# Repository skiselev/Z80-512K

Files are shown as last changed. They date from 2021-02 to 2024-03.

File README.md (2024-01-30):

# Z80-512K
Z80 CPU, 512 KiB SRAM, and 512 KiB Flash ROM module for RCBus systems

## Table of Content
* [Overview](#overview)
  * [Specifications](#specifications)
* [Assembly Instructions](#assembly-instructions)
* [Hardware Documentation](#hardware-documentation)
  * [Schematic and PCB Layout](#schematic-and-pcb-layout)
  * [Input/Output Ports](#inputoutput-ports)
  * [Connectors](#connectors)
  * [Bill of Materials](#bill-of-materials)
  * [CPLD Fuse Map](#cpld-fuse-map)
* [Release Notes](#release-notes)
  * [Changes](#changes)
  * [Known Issues](#known-issues)
* [Red Tape](#red-tape)
  * [Licensing](#licensing)
  * [Trademarks](#trademarks)

## Overview
Z80-512K is an RCBus and RC2014* compatible module, designed to run RomWBW firmware including CP/M, ZSDOS, and various applications under these OSes. Z80-512K combines functionality of the following RC2014* modules on a single module, thus saving space on the backplane:
* Z80 CPU Module
* 512k ROM 512k RAM Module
* Clock and Reset Module

In addition to these functions, Z80-512K includes programmable CLK2 clock divider, support for battery-backed SRAM, power failure NMI generation, and a watchdog.

Minimal CP/M computer system can be built using Z80-512K module, a backplane, and a serial port module, such as Z80 SIO or MC68B50 ACIA. For configurable baud rate settings, it is recommened to use serial modules that can use CLK2 as a clock, for example Steve Cousins' [SC716](https://smallcomputercentral.com/sc716-rcbus-z80-sio-2-serial-module/) or [SC725](https://smallcomputercentral.com/sc725-rcbus-serial-and-timer-module/) modules.  Additional storage module is not required, since RomWBW utilizes part of ROM and SRAM for ROM and RAM disks respecitvely, but a Compact Flash module can be added for additional storage. For a compact system, a 3-slot [SC723](https://smallcomputercentral.com/sc723-rcbus-backplane-3/) can be used.

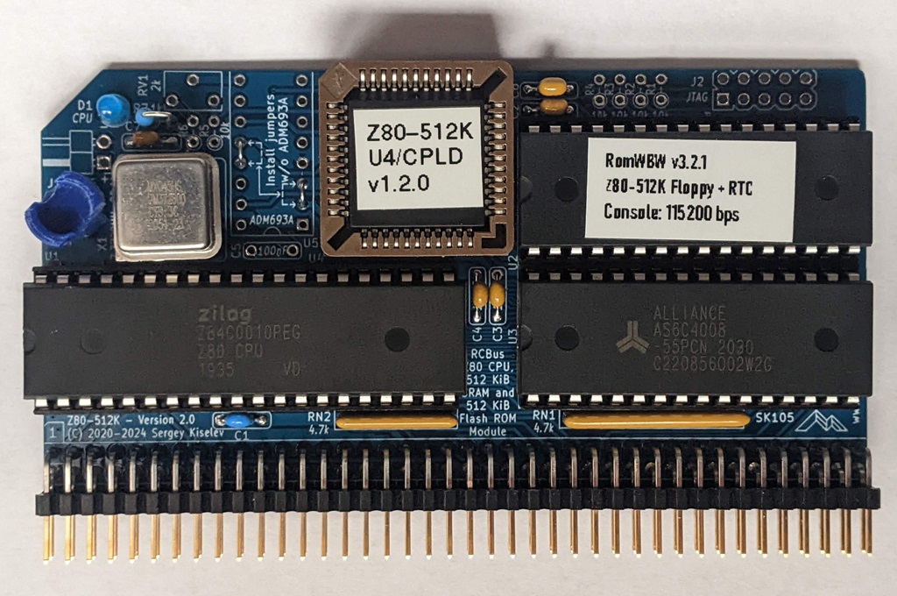
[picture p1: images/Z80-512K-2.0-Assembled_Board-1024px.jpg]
Z80-512K Assembled Board


### Specifications
* Processor: Zilog* Z80 CPU (CMOS version - Z84C00)
* Memory: 512 KiB battery-backed SRAM, 512 KiB Flash ROM, Zeta SBC V2 compatible memory pager
* Bus: RC2014* compatible
* Microprocessor Supervisor:
  * Reset generation
  * SRAM battery backup
  * Power failure NMI
  * Watchdog

## Assembly Instructions

Please refer to [Assembly Instructions](Assembly_Instructions.md) document

## Hardware Documentation

### Documentation for the Previous Versions

* [Version 1.2](https://github.com/skiselev/Z80-512K/tree/v1.2)

### Schematic and PCB Layout

* [Schematic - Version 2.0](KiCad/Z80-512K-Schematic-2.0.pdf)
* [PCB Layout - Version 2.0](KiCad/Z80-512K-Board-2.0.pdf)

### Input/Output Ports
Z80-512K uses an Atmel* ATF1504AS CPLD (complex programmable logic device) to implement Zeta SBC V2 compatible memory pager, watchdog control, and UART clock divider.
These functions are configured using registers that are accessible using I/O ports. Upon reset, the configuration registers are set to values that result in an RC2014 compatible configuration, so that RomWBW RCZ80_std.rom image can be used without any modifications.

The following I/O ports are implemented in the CPLD:

#### 0x6D - CONFIG - UART Clock Divisor and Watchdog Configuration (Read/Write)

Bits 0-4 define the ratio the 7.3728 MHz CPU clock (CLK1) is divided by to produce UART clock (CLK2).
The output clock can be calculated using the following formula: **f<sub>CLK2</sub> (Hz) = 7372800 / (3<sup>m</sup> * 2<sup>n</sup>)**, where **m** is bit 4 of **CONFIG** register (0 or 1), and **n** are bits 3-0 of **CONFIG** register (0 to 15)

Port | Bit # | Function                | Value = 0             | Value = 1
-----|-------|-------------------------|-----------------------|----------------------
0x6D | 0     | Divide CPU clock by 2   | Disable divide by 2   | Enable divide by 2
0x6D | 1     | Divide CPU clock by 4   | Disable divide by 4   | Enable divide by 4
0x6D | 2     | Divide CPU clock by 16  | Disable divide by 16  | Enable divide by 16
0x6D | 3     | Divide CPU clock by 256 | Disable divide by 256 | Enable divide by 256
0x6D | 4     | Divide CPU clock by 3   | Disable divide by 3   | Enable divide by 3

* Note: Bits 0-4 are reset to '0' on power-on or reset, so that the divide ratio is set to 1 and the CLK2 frequency is 7.3728 MHz

Bit 5 enables or disables the watchdog and controls the generation of watchdog (WDOG) signal. On the board the WDOG signal is connected to the CPU supervisor IC U5 ADM693A. The CPU supervisor will reset the board if WDOG signal is not pulsed within 1.6 seconds.
When watchdog is disabled, the /M1 signal is routed to WDOG signal, so that it is pulsed on every instruction fetch. When watchdog is enabled, the WDOG signal should be pulsed by writting to WDOG register, port 0x6F (see below) in intervals of less than 1.6 seconds.

Port | Bit # | Function                | Value = 0             | Value = 1
-----|-------|-------------------------|-----------------------|----------------------
0x6D | 5     | Watchdog enable         | Disable watchdog      | Enable watchdog

* Note: Bit 5 is reset to '0' on power-on or reset, so that watchdog is disabled

Port | Bit # | Function                                         | Value
-----|-------|--------------------------------------------------|-----------------------
0x6D | 7-6   | Not implemented                                  | Should be set to 0

#### 0x6F - WDOG - Reset Watchdog (Write-only)

Any write to this port pulses the WDOG signal, which resets the watchdog in the CPU supervisor U5

Port | Bit # | Function                | Value
-----|-------|-------------------------|---------------------------------------------
0x6F | N/A   | WDOG - Reset watchdog   | Any write to this port resets the watchdog

#### 0x78-0x7B - MPGSEL - Memory Page Select Registers (Write-only)

Port | Bit # | Function                                         | Value
-----|-------|--------------------------------------------------|-----------------------
0x78 | 5-0   | MPGSEL_0 - Page number for bank #0 0x0000-0x3FFF | 0-31 - Page number
0x78 | 7-6   | Not implemented                                  | Should be set to 0
0x79 | 5-0   | MPGSEL_1 - Page number for bank #1 0x4000-0x7FFF | 0-31 - Page number
0x79 | 7-6   | Not implemented                                  | Should be set to 0
0x7A | 5-0   | MPGSEL_3 - Page number for bank #2 0x8000-0xBFFF | 0-31 - Page number
0x7A | 7-6   | Not implemented                                  | Should be set to 0
0x7B | 5-0   | MPGSEL_4 - Page number for bank #3 0xC000-0xFFFF | 0-31 - Page number
0x7B | 7-6   | Not implemented                                  | Should be set to 0

#### 0x7Ch - MPGENA - Enable Memory Paging (Write-only)

Port | Bit # | Function                | Value = 0             | Value = 1
-----|-------|-------------------------|-----------------------|----------------------
0x7C | 0     | Memory paging enable    | Disable memory paging | Enable memory paging

* Note: The register is reset to '0' on power-on or reset, which disables the memory paging. When memory paging is disabled the memory page 0 (lower 16 KiB of the Flash ROM) is mapped to all banks.

Port | Bit # | Function                                         | Value
-----|-------|--------------------------------------------------|-----------------------
0x7C | 7-1   | Not implemented                                  | Should be set to 0

### Connectors

#### J1 - NVRAM Battery
Connect 3V battery for SRAM backup to this connector.

**Important: If the SRAM battery backup is not desired, short J1 with a jumper. Do not leave this connector open.**

Pin | Signal Name | Description
--- | ----------- | -----------
1   | VBAT        | Positive terminal - +3V
2   | GND         | Negative terminal - ground

#### J2 - JTAG - CPLD
This connector can be used to program the U4 CPLD

Pin  | Signal Name | Description      | Pin  | Signal Name | Description
---- | ----------- | ---------------- | ---- | ----------- | ----------------
1    | TCK         | Test Clock       | 2    | GND         | Ground
3    | TDO         | Test Data Output | 4    | 5V          | 5V Power Supply - Output to JTAG adapter
5    | TMS         | Test Mode Select | 6    | NC          | No Connect
7    | NC          | No Connect       | 8    | NC          | No Connect
9    | TDI         | Test Data Input  | 10   | GND         | Ground

#### J3, J4 - RC2014* Bus
Pin   | Signal Name | Description                             | Pin   | Signal Name | Description
----- | ----------- | --------------------------------------- | ----- | ----------- | -----------
J3-1  | A15         | Address A15; Output                     | J3-41 | p41         | Reserved; Not connected
J3-2  | A14         | Address A14; Output                     | J3-42 | /BAI        | Bus Acknowledge In; Not connected
J3-3  | A13         | Address A13; Output                     | J3-43 | /BAO        | Bus Acknowledge Out; Not connected
J3-4  | A12         | Address A12; Output                     | J3-44 | p44         | Reserved; Not connected
J3-5  | A11         | Address A11; Output                     | J3-45 | p45         | Reserved; Not connected
J3-6  | A10         | Address A10; Output                     | J3-46 | p46         | Reserved; Not connected
J3-7  | A9          | Address A9; Output                      | J3-47 | p47         | Reserved; Not connected
J3-8  | A8          | Address A8; Output                      | J3-48 | p48         | Reserved; Not connected
J3-9  | A7          | Address A7; Output                      | J3-49 | A23         | Address A23; Input; Not connected
J3-10 | A6          | Address A6; Output                      | J3-50 | A22         | Address A22; Input; Not connected
J3-11 | A5          | Address A5; Output                      | J3-51 | A21         | Address A21; Input; Not connected
J3-12 | A4          | Address A4; Output                      | J3-52 | A20         | Address A20; Input; Not connected
J3-13 | A3          | Address A3; Output                      | J3-53 | A19         | Address A19; Input; Not connected
J3-14 | A2          | Address A2; Output                      | J3-54 | A18         | Address A18; Input; Not connected
J3-15 | A1          | Address A1; Output                      | J3-55 | A17         | Address A17; Input; Not connected
J3-16 | A0          | Address A0; Output                      | J3-56 | A16         | Address A16; Input; Not connected
J3-17 | GND         | Ground                                  | J3-57 | GND         | Ground
J3-18 | VCC         | Power Supply - +5V                      | J3-58 | VCC         | Power Supply - +5V
J3-19 | /M1         | Machine Cycle One; Output               | J3-59 | /RFSH       | DRAM refresh; Output
J3-20 | /RESET      | Reset; Output                           | J3-60 | PAGE         | Page ROM/RAM input; Not connected
J3-21 | CLK1        | CPU Clock; Output                       | J3-61 | CLK2        | UART Clock (programmable); Output
J3-22 | /INT        | Interrupt; Input                        | J3-62 | /BUSACK     | DMA Bus Acknowledge; Output
J3-23 | /MREQ       | Memory Request; Output                  | J3-63 | /HALT       | Halt; Output
J3-24 | /WR         | Write Request; Output                   | J3-64 | /BUSREQ     | DMA Bus Request; Input
J3-25 | /RD         | Read Request; Output                    | J3-65 | /WAIT       | Wait; Input
J3-26 | /IORQ       | Input/Output Request; Output            | J3-66 | /NMI        | Non-maskable Interrupt; Input
J3-27 | D0          | Data D0; Input/Output                   | J3-67 | D8          | Data D8; Input/Output; Not connected
J3-28 | D1          | Data D1; Input/Output                   | J3-68 | D9          | Data D9; Input/Output; Not connected
J3-29 | D2          | Data D2; Input/Output                   | J3-69 | D10         | Data D10; Input/Output; Not connected
J3-30 | D3          | Data D3; Input/Output                   | J3-70 | D11         | Data D11; Input/Output; Not connected
J3-31 | D4          | Data D4; Input/Output                   | J3-71 | D12         | Data D12; Input/Output; Not connected
J3-32 | D5          | Data D5; Input/Output                   | J3-72 | D13         | Data D13; Input/Output; Not connected
J3-33 | D6          | Data D6; Input/Output                   | J3-73 | D14         | Data D14; Input/Output; Not connected
J3-34 | D7          | Data D7; Input/Output                   | J3-74 | D15         | Data D15; Input/Output; Not connected
J3-35 | TX          | Channel 1, Transmit Data; Not Connected | J3-75 | TX2         | Channel 2, Transmit Data; Not Connected
J3-36 | RX          | Channel 1, Receive Data; Not Connected  | J3-76 | RX2         | Channel 2, Receive Data; Not Connected
J3-37 | /IRQ1       | Interrupt Request 1; Not connected      | J3-77 | /IRQ2       | Interrupt Request 2; Not connected
J3-38 | IEI         | Interrupt Enable In; Not connected      | J3-78 | p78         | Reserved; Not connected
J3-39 | IEO         | Interrupt Enable Out; Not connected     | J3-79 | p79         | Reserved; Not connected
J3-40 | USER4       | User Pin 4; Not connected               | J3-80 | USER8       | User Pin 8; Not connected

### Bill of Materials

#### Version 2.0

Mouser projects - all components except of the PCB:
* [Z80-512K V2 project](https://www.mouser.com/ProjectManager/ProjectDetail.aspx?AccessID=a4dc766274) - All components except of the PCB, CPU supervisor (optional), and JTAG header (optional).
* [Z80-512K V2 - CPU Supervisor project](https://www.mouser.com/ProjectManager/ProjectDetail.aspx?AccessID=bce8da5b24) - Components for CPU supervisor (optional).
* [Z80-512K V2 - JTAG Header project](https://www.mouser.com/ProjectManager/ProjectDetail.aspx?AccessID=c965bd23ef) - Components for JTAG header (optional).

Z80-512K project on Tindie:
* [Complete kit](https://www.tindie.com/products/weird/z80-512k-rcbus-module-kit/).
* [Z80-512K PCB, a preprogrammed CPLD and optionally a Flash ROM](https://www.tindie.com/products/weird/z80-512k-rcbus-module-pcb-and-cpld/).

Component type     | Reference | Description                                 | Quantity | Possible sources and notes 
------------------ | --------- | ------------------------------------------- | -------- | --------------------------
PCB                |           | Z80-512K PCB - Version 2.0                  | 1        | Buy from my Tindie store: [Complete kit](https://www.tindie.com/products/weird/z80-512k-rc2014-compatible-module-kit/); [Z80-512K PCB, a preprogrammed CPLD and optionally a Flash ROM](https://www.tindie.com/products/weird/z80-512k-rc2014-compatible-module-pcb-and-cpld/), or order from a PCB manufacturer of your choice using provided Gerber or KiCad files
Integrated Circuit | U1        | Z84C00xxPEG - Z80 CPU, CMOS, 40 pin DIP     | 1        | Mouser [692-Z84C0010PEG](https://www.mouser.com/ProductDetail/692-Z84C0010PEG)
Integrated Circuit | U2        | SST39SF040 - 512 KiB Flash ROM, 32 pin DIP  | 1        | Mouser [804-39SF0407CPHE](https://www.mouser.com/ProductDetail/804-39SF0407CPHE)
Integrated Circuit | U3        | AS6C4008 - 512 KiB SRAM, 32 pin DIP         | 1        | Mouser [913-AS6C4008-55PCN](https://www.mouser.com/ProductDetail/913-AS6C4008-55PCN)
Integrated Circuit | U4        | ATF1504AS - CPLD, 64 macrocells, 44 pin PLCC| 1        | Mouser [556-AF1504AS10JU44](https://www.mouser.com/ProductDetail/556-AF1504AS10JU44); Possible alternative: Altera EPM7064SLC44-10
Integrated Circuit | U5        | ADM693A - Microprocessor Supervisory Circuit| 1        | Mouser [584-ADM693ANZ](https://www.mouser.com/ProductDetail/584-ADM693ANZ). Optional: CPU reset, watchdog, and power failure NMI. Possible alternatives: MAX693, LTC693, ADM691, MAX691, LTC691, ADM695, MAX695, LTC965, LTC1235
Oscillator         | X1        | 7.3728 MHz, CMOS oscillator, half can       | 1        | Mouser [774-MXO45HS-3C-7.3](https://www.mouser.com/ProductDetail/774-MXO45HS-3C-7.3) or [520-2200B-073](https://www.mouser.com/ProductDetail/520-2200B-073/)
LED                | D1        | LED indicator, 3 mm, blue                   | 1        | Mouser [710-151033BS03000](https://www.mouser.com/ProductDetail/710-151033BS03000)
Connector          | J1        | 2 pin header with friction lock, right angle| 1        | Mouser [571-6404572](https://www.mouser.com/ProductDetail/571-6404572). Optional: battery-backed SRAM
Pin Header         | J2        | 2x5 pin header, 2.54 mm pitch, vertical     | 1        | Mouser [649-77313-118-10LF](https://www.mouser.com/ProductDetail/649-77313-118-10LF). Optional: JTAG header
Pin Header         | J3        | 2x40 pin header, 2.54 mm pitch, right angle | 1        | Mouser [517-5121TG](https://www.mouser.com/ProductDetail/517-5121TG)
Capacitor          | C1        | 10 uF, 25V, MLCC, 5 mm pitch                | 1 | Mouser [810-FG28X5R1E106MR06](https://www.mouser.com/ProductDetail/810-FG28X5R1E106MR06)
Capacitor          | C2 - C7   | 0.1 uF, 50V, MLCC, 5 mm pitch               | 6        | Mouser [594-K104K15X7RF53H5](https://www.mouser.com/ProductDetail/594-K104K15X7RF53H5). Note: C5 is optional, required if U5 installed
Resistor Array     | RN1       | 4.7 kohm, bussed, 9 pin SIP                 | 1        | Mouser [652-4609X-1LF-4.7K](https://www.mouser.com/ProductDetail/652-4609X-1LF-4.7K) or [652-4609X-AP1-472LF](https://www.mouser.com/ProductDetail/652-4609X-AP1-472LF)
Resistor Array     | RN2       | 4.7 kohm, bussed, 6 pin SIP                 | 1        | Mouser [652-4606X-1LF-4.7K](https://www.mouser.com/ProductDetail/652-4606X-1LF-4.7K) or [652-4606X-AP1-472LF](https://www.mouser.com/ProductDetail/652-4606X-AP1-472LF)
Resistor           | R1 - R5   | 10 kohm, 0.25 W, 1% tolerance, axial        | 5        | Mouser [603-MFR-25FRF5210K](https://www.mouser.com/ProductDetail/603-MFR-25FRF5210K). Optional: R1 - R4 - JTAG header, R5 - Power failure NMI	
Resistor           | R6        | 29.4 kohm, 0.25 W, 1% tolerance, axial      | 1        | Mouser [603-MFR-25FBF52-29K4](https://www.mouser.com/ProductDetail/603-MFR-25FBF52-29K4). Optional: Power failure NMI
Resistor           | R7        | 1 kohm, 0.25 W, axial                       | 1        | Mouser [603-MFR-25FRF521K](https://www.mouser.com/ProductDetail/603-MFR-25FRF521K)
Trimmer Resistor   | RV1       | 2 kohm, through hole                        | 1        | Mouser [652-3362W-1-202LF](https://www.mouser.com/ProductDetail/652-3362W-1-202LF). Optional: Power failure NMI
IC Socket          | U1        | 40 pin DIP                                  | 1        | Mouser [517-4840-6000-CP](https://www.mouser.com/ProductDetail/517-4840-6000-CP)
IC Socket          | U2, U3    | 32 pin DIP                                  | 2        | Mouser [517-4832-6000-CP](https://www.mouser.com/ProductDetail/517-4832-6000-CP)
IC Socket          | U4        | 44 pin PLCC, through hole                   | 1        | Mouser [517-8444-11B1-RK-TP](https://www.mouser.com/ProductDetail/517-8444-11B1-RK-TP)
IC Socket          | U5        | 16 pin DIP                                  | 1        | Mouser [517-4816-3000-CP](https://www.mouser.com/ProductDetail/517-4816-3000-CP). Optional: CPU reset, watchdog, and power failure NMI. Install two wire jumpers as indicated on the PCB if U5 is not used.
Oscillator Socket  | X1        | 4 pin DIP, Half Can                         | 1        | Mouser [535-1108800](https://www.mouser.com/ProductDetail/535-1108800)
Jumper             | J1        | Shunt, 2 pin 2.54 mm pitch                  | 1        | Mouser [806-SX1100-B](https://www.mouser.com/ProductDetail/806-SX1100-B). Optional: install if battery is not used, but U5 is installed
Connector Contacts | J1        | Connector contact                           | 2        | Mouser [571-14453361](https://www.mouser.com/ProductDetail/571-14453361). Optional: connector for battery enclosure, install for battery-backed SRAM
Connector Housing  | J1        | 2 pin housing, 2.54 mm pitch                | 1        | Mouser [571-13758202](https://www.mouser.com/ProductDetail/571-13758202). Optional: connector for battery enclosure, install for battery-backed SRAM
Battery holder     | J1        | 2xAAA battery enclosure with switch         | 1        | Mouser [12BH421/CS-GR](https://www.mouser.com/ProductDetail/12BH421-CS-GR). Optional: battery enclosure, install for battery-backed SRAM

### CPLD Fuse Map

Z80-512K uses Atmel ATF1504AS or Intel*/Altera* EPM7064STC44 CPLD (U4) CPLD for memory pager and varous other logic. [Atmel CPLD fuse map](CPLD/output_files/Z80_512K.jed), [Altera CPLD fuse map](CPLD/output_files/Z80_512K.pof), and the CPLD source code are provided in [CPLD](CPLD) directory of this repository. Use [ATMISP](https://www.microchip.com/en-us/products/fpgas-and-plds/spld-cplds/pld-design-resources) software to program Atmel CPLD. Use free [Altera Quartus II 13.0sp1 Web Edition](https://fpgasoftware.intel.com/13.0sp1/) to program Altera CPLD. Newer Quartus versions do not support Altera MAX7000 CPLDs.

## Release Notes

### Changes

* Version 2.0:
  * Update form factor from RC2014* compatible to RCBus
  * Move the battery connector to the edge of the board
  * Make U5, CPU Supervisor IC, optional. Add information on the silkscreen for the configuration without U5

* Version 1.2
  * Add CPU LED back. Use WDOG signal to control the LED

* Version 1.1
  * Add CPLD STATUS register read back capability
  * Remove LEDs
  * Improve PCB routing: use wider traces where possible, better ground fill
  * Add signal names on the bottom silk screen

* Version 1.0
  * Initial version

### Known Issues

* Version 1.1
  * No diagnostic LEDs
    * Workaround: Connect an external LED in series with 1 kohm resistor between U5 pin 11 (WDOG signal) and VCC signal.

* Version 1.0
  * No CPLD STATUS register read back
    * Workaround: Program CPLD with the version 1.1 fuse map. Cut LED_OUT trace at D2 LED (negative terminal), connect U4 pin 36 to U1 pin 21 (RD signal) with a piece of wire. If diagnostic LED is needed, connect negative terminal of the LED to U5 pin 11 (WDOG signal)

### Wishlist
* Consider using JST connector for the battery
  * Lower profile than TE latchable connector
  * Ready-made battery holders with JST connectors, such as [Adafruit 4191](https://www.adafruit.com/product/4191) can be used
* Add RCBUs logo

## Red Tape

### Licensing

Z80-512K is an open source hardware project certified by [Open Source Hardware Association](https://www.oshwa.org/), certification UID is [US001061](https://certification.oshwa.org/us001061.html). The hardware design itself, including schematic and PCB layout design files are licensed under the strongly-reciprocal variant of [CERN Open Hardware Licence version 2](license-cern_ohl_s_v2.txt). The CPLD VHDL code is licensed under [GNU General Public License v3](license-gpl-3.0.txt). Documentation, including this file, is licensed under the [Creative Commons Attribution-ShareAlike 4.0 International License](license-cc-by-sa-4.0.txt).

CERN-OHL-2.0-S, GPL-3.0, CC-BY-SA-4.0

### Trademarks

* "RC2014" is a registered trademark of RFC2795 Ltd.
* Other names and brands may be claimed as the property of others.

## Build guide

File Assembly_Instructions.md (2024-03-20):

# Z80-512K - Assembly Instructions

## Prerequisites

### Tools, Equipment, and Supplies

* Soldering iron with a fine tip. Temperature controlled soldering station is recommended
* Needle nose pliers for forming components' leads
* Small side cutters for cutting components' leads
* Universal programmer capable of programming SST39F040 Flash ROM ICs. For example, MiniPro TL866CS or MiniPro TL866A
* Multimeter with frequency measurement, an oscilloscope, or a logic analyzer can be beneficial for troubleshooting
* Desk lamp, magnifying glass
* Solder suitable for soldering electronics. For example: rosin core Sn63/Pb37, Sn60/Pb40, or a lead-free solder such as Sn96.5/Ag3.0/Cu0.5 (sometimes referred to as SAC305)
* Solder wick for removing excess of solder
* 99% Isopropyl Alcohol for removing the excess of flux after soldering
* Lint free wipes, used toothbrush, cotton swabs for cleaning the PCB before and after soldering

### Parts

The table below shows the images of the components included in the kit. The up to date list of parts provided in the [Bill of Materials](README.md#bill-of-materials) section of the [README.md](README.md) file. It also provides the recommended sources for the parts.

Image                                                                                           | Reference | Description                                          | Quantity
----------------------------------------------------------------------------------------------- | --------- | ---------------------------------------------------- | --------
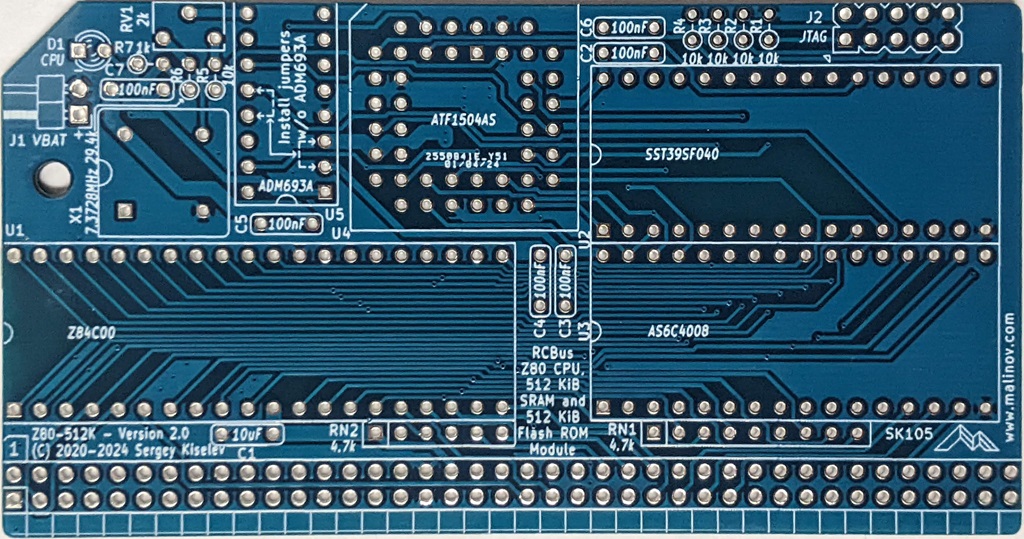
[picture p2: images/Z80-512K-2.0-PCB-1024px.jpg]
PCB - Z80-512K v2.0
           | PCB       | Z80-512K PCB - Version 2.0                           | 1
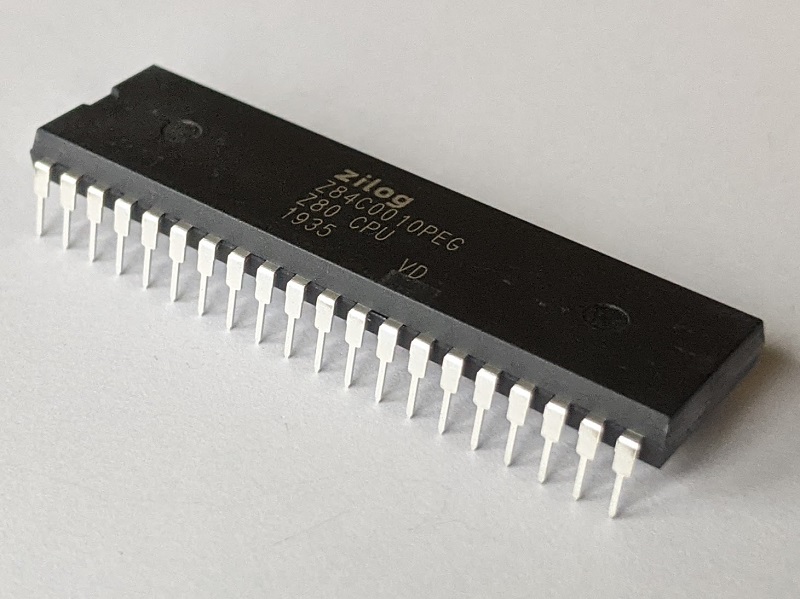
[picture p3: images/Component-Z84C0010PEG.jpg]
CPU - Z84C0010PEG
               | U1        | Z84C0010PEG - Z80 CPU, CMOS, 40 pin DIP              | 1
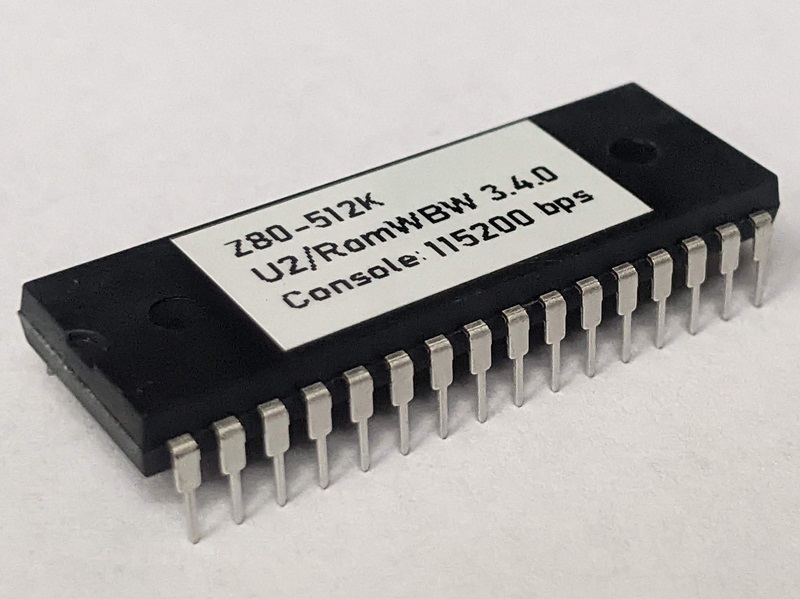
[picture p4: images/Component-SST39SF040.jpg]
Flash ROM - SST39SF040
           | U2        | SST39SF040 - 512 KiB Flash ROM, 32 pin DIP           | 1
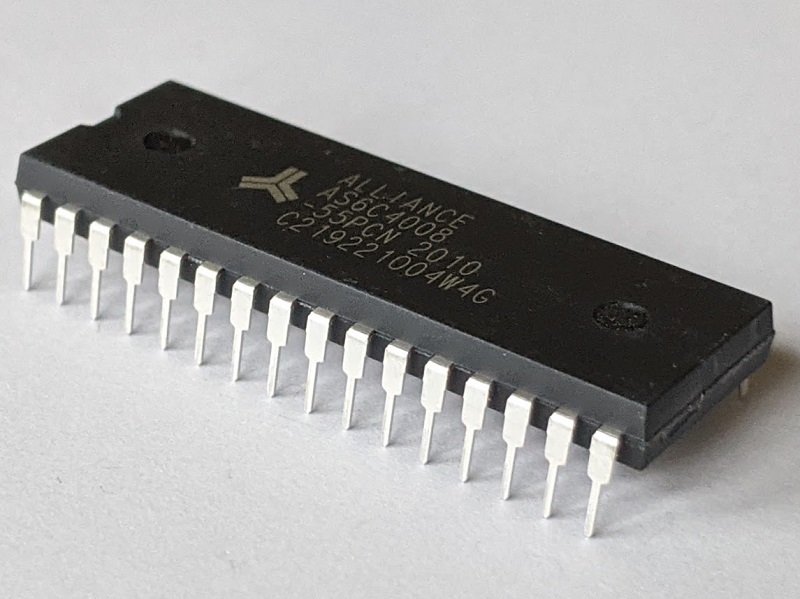
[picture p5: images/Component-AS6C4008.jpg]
SRAM - AS6C4008
                    | U3        | AS6C4008 - 512 KiB SRAM, 32 pin DIP                  | 1
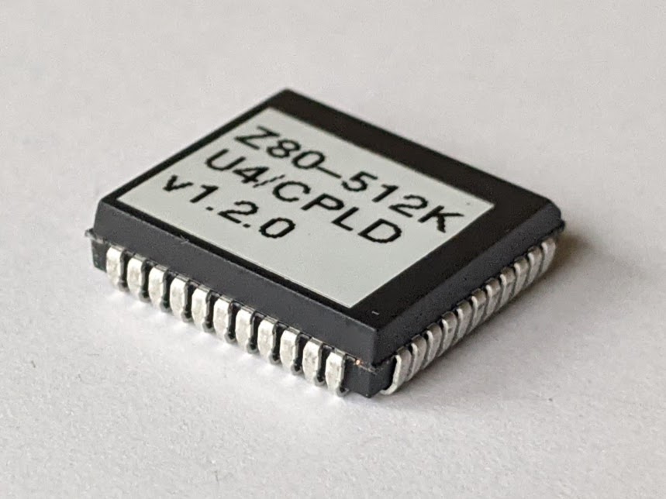
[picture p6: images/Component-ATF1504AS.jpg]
CPLD - ATF1504AS
                  | U4        | ATF1504AS - CPLD, 64 macrocells, 44 pin PLCC         | 1
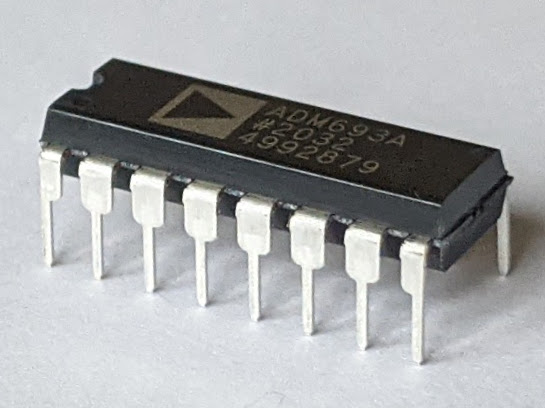
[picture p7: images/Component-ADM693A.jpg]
Supervisor - ADM693A
                | U5        | ADM693A - Microprocessor Supervisory Circuit         | 1 (optional)
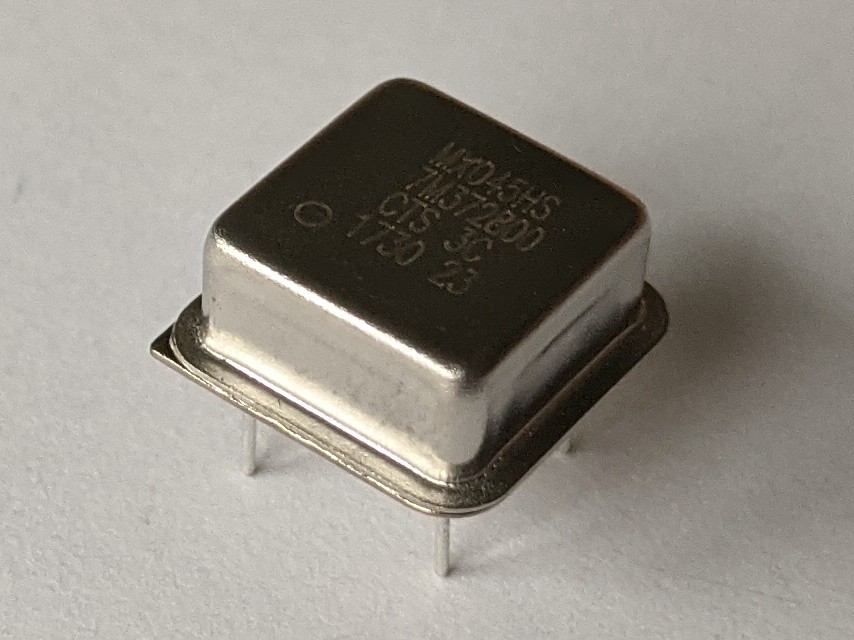
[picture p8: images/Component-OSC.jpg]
Oscillator - 7.3728 MHz
                 | X1        | 7.3728 MHz, CMOS oscillator, half can                | 1
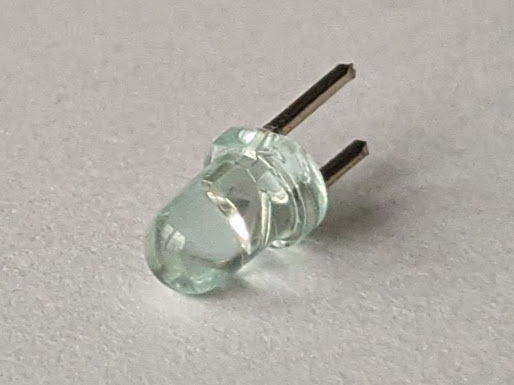
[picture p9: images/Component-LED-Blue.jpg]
LED - 3mm - Blue
                   | D1        | LED indicator, 3 mm, blue                            | 1 (optional)
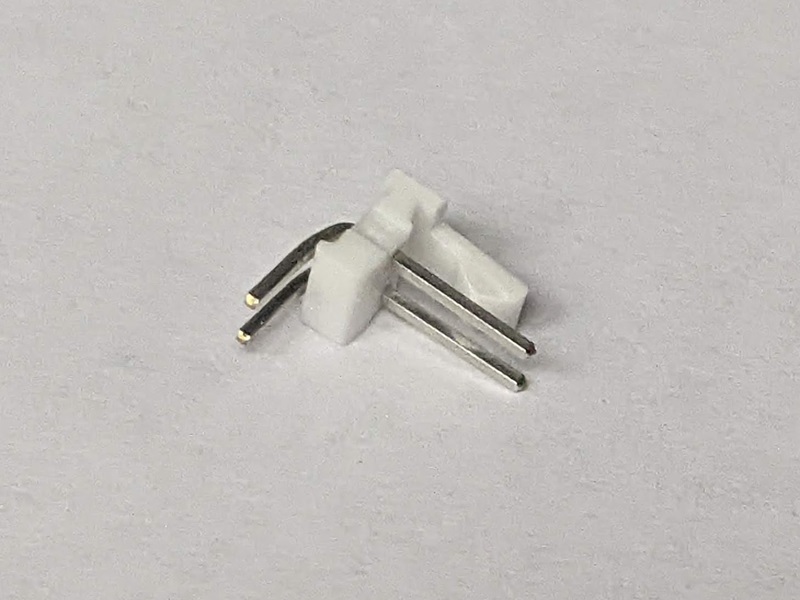
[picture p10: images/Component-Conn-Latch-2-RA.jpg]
Friction Lock Connector
     | J1        | 2 pin header with friction lock, right angle         | 1
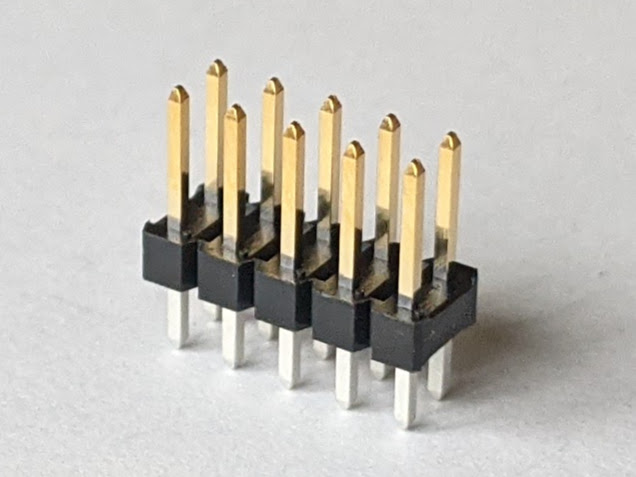
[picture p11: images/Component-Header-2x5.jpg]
Pin Header 2x5
                   | J2        | 2x5 pin header, 2.54 mm pitch, vertical              | 1 (optional)
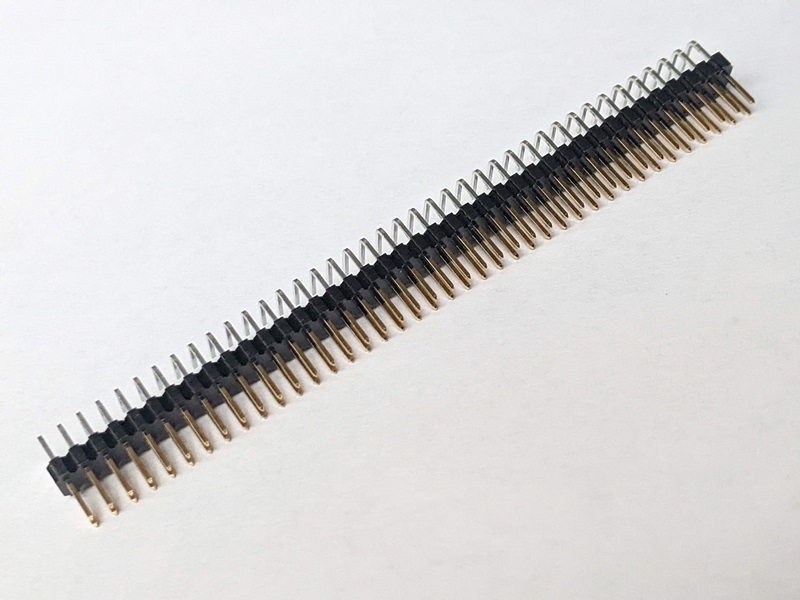
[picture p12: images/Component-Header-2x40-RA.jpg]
Pin Header 2x40 Right Angle
  | J3        | 2x40 pin header, 2.54 mm pitch, right angle          | 1
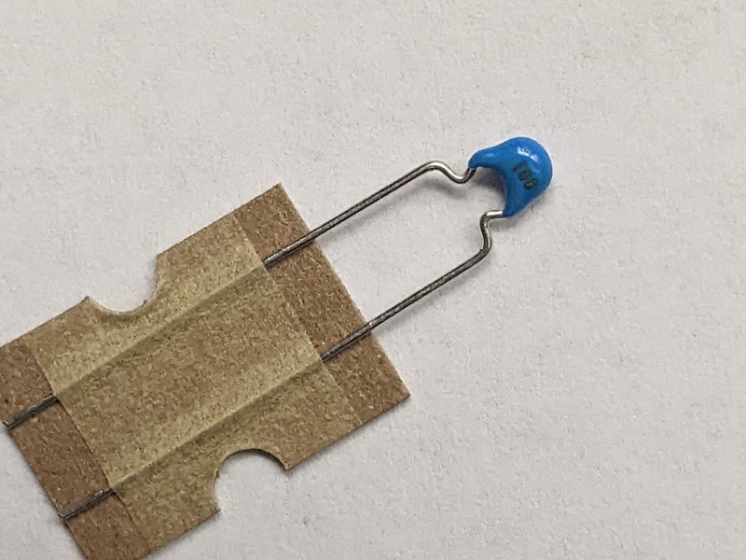
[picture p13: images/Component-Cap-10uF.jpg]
Ceramic Capacitor - 10uF
           | C1        | Capacitor, 10 uF, 25V, MLCC, 5 mm pitch              | 1
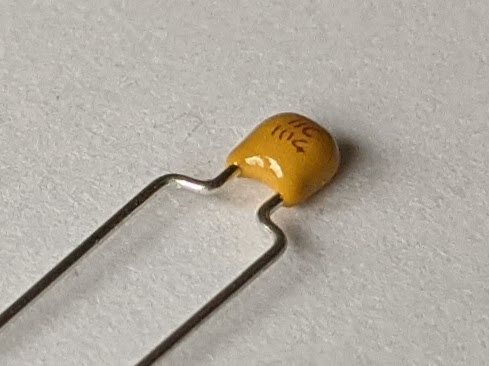
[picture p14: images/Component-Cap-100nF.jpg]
Ceramic Capacitors - 0.1uF
        | C2 - C7   | Capacitor, 0.1 uF, 50V, MLCC, 5 mm pitch             | 6
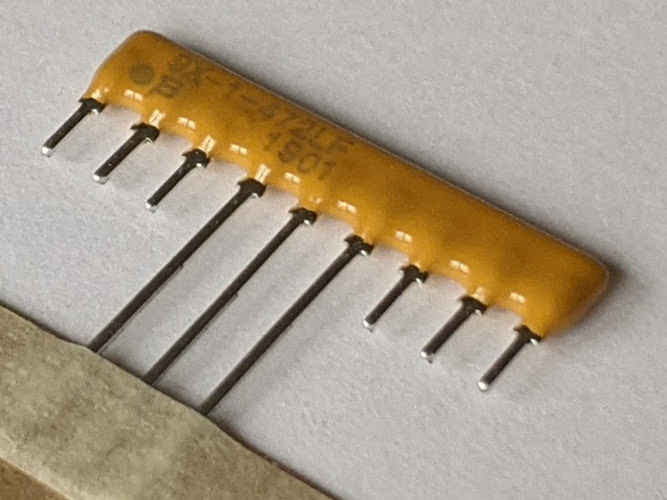
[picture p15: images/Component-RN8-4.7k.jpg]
Resistor Network - 8x4.7k
          | RN1       | Resistor Network, 4.7 kohm, bussed, 9 pin SIP        | 1
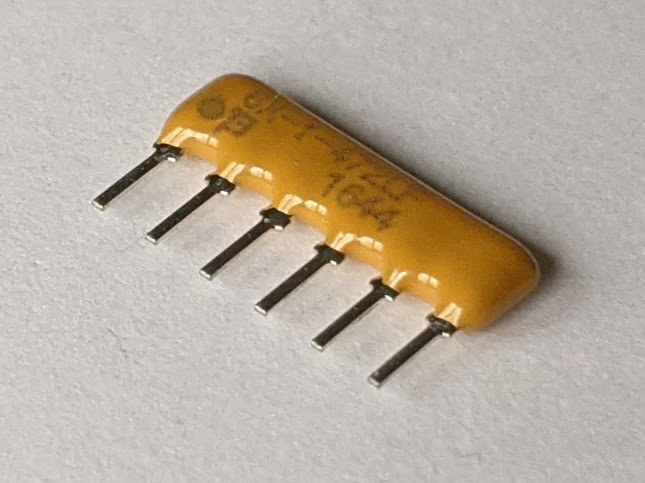
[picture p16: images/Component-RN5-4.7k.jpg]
Resistor Network - 5x4.7k
          | RN2       | Resistor Network, 4.7 kohm, bussed, 6 pin SIP        | 1
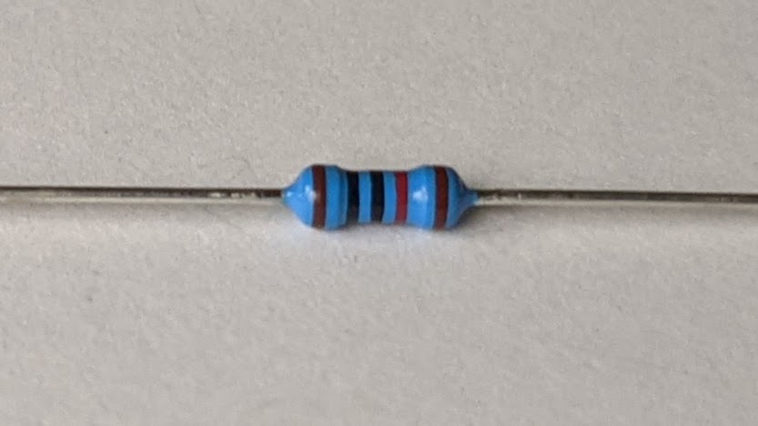
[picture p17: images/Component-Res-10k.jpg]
Resistor - 10k
                      | R1 - R5   | Resistor, 10 kohm, 0.25 W, 1% tolerance, axial       | 5 (optional)
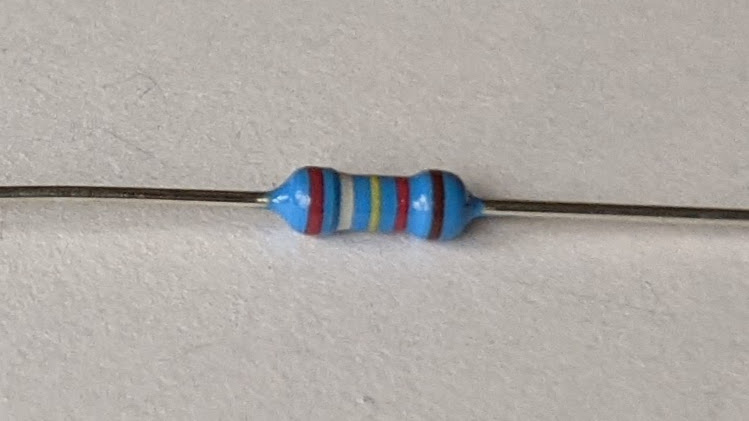
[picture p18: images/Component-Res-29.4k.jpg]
Resistor - 29.4k
                  | R6        | Resistor, 29.4 kohm, 0.25 W, 1% tolerance, axial     | 1 (optional)
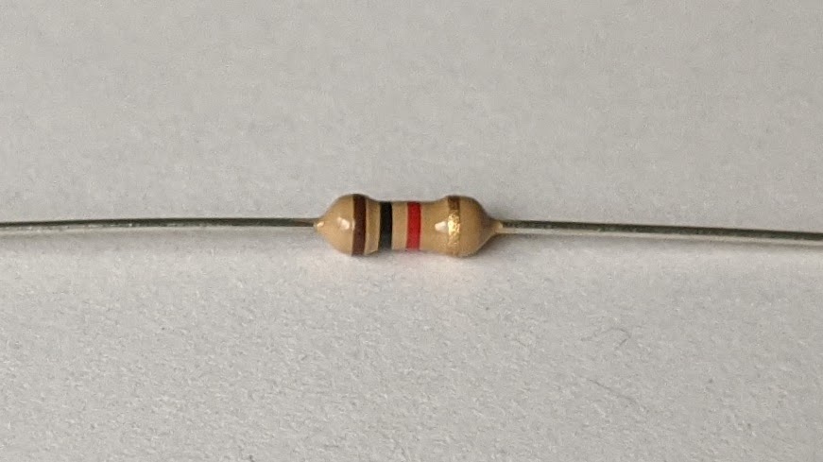
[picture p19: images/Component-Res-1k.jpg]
Resistor - 1k
                        | R7        | Resistor, 1 kohm, 0.25 W, axial                      | 1
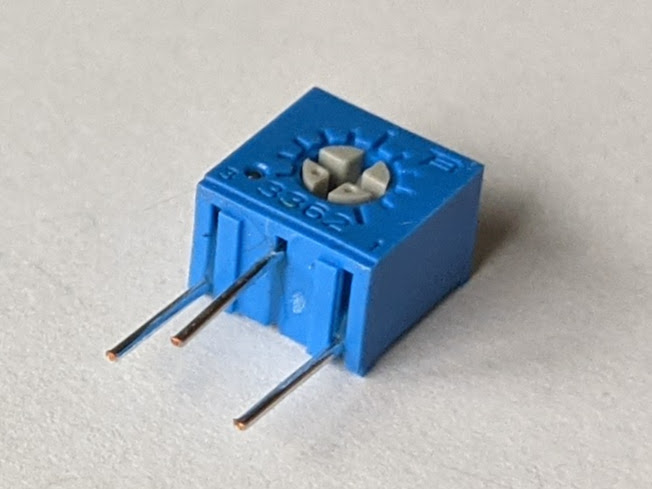
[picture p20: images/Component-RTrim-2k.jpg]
Trimmer Resistor - 2k
              | RV1       | Trimmer Resistor, 2 kohm, through hole               | 1 (optional)
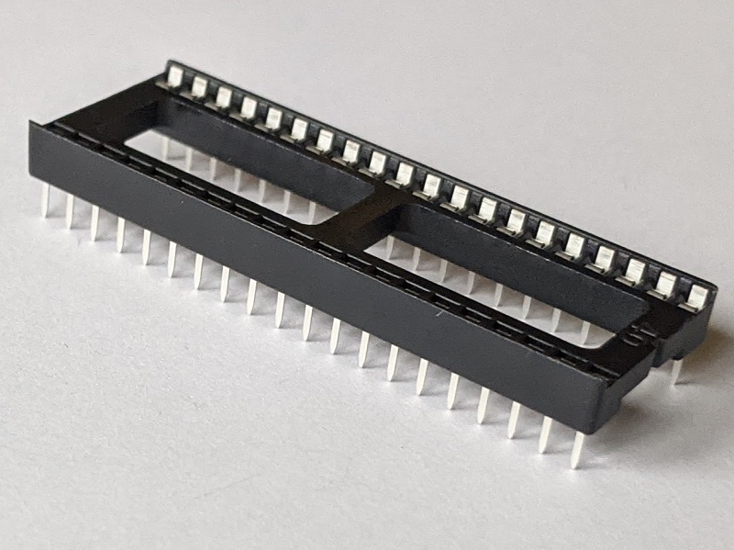
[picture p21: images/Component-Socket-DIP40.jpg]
IC Socket - DIP40
              | U1        | Integrated circuit socket, 40 pin DIP                | 1
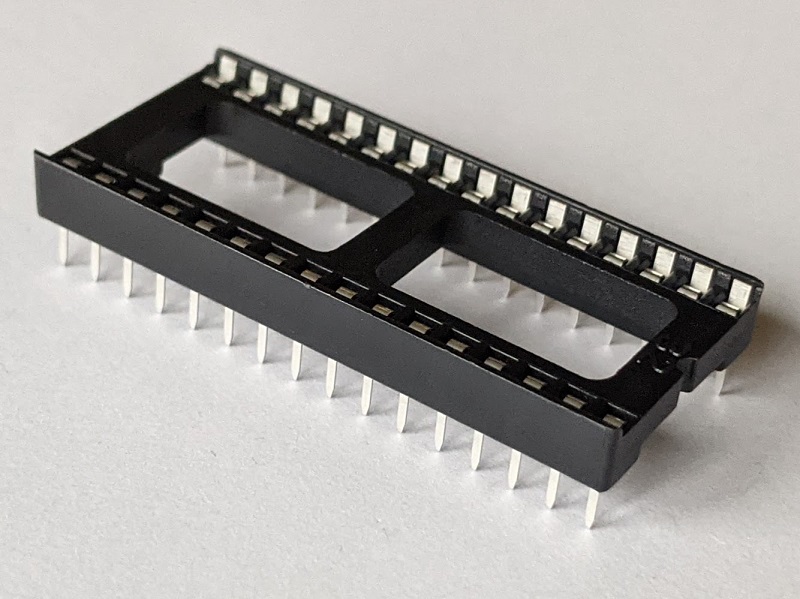
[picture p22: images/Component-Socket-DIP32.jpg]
IC Socket - DIP32
              | U2, U3    | Integrated circuit socket, 32 pin DIP                | 2
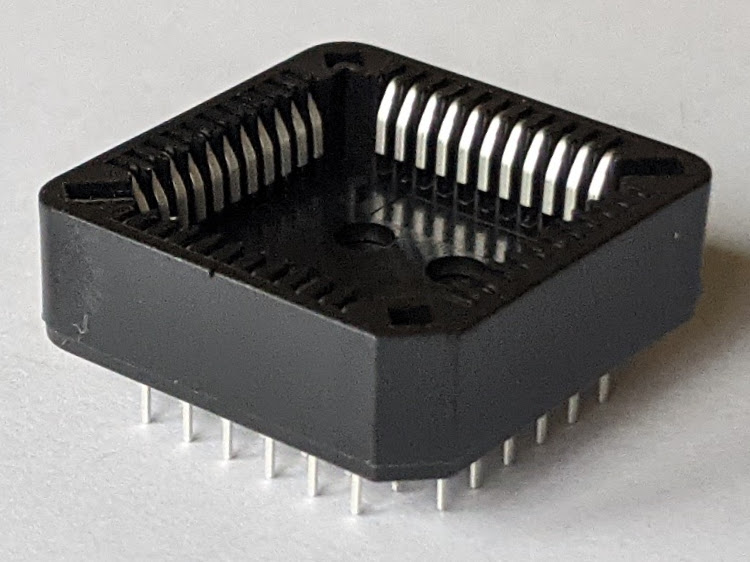
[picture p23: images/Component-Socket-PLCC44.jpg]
IC Socket - PLCC44
            | U4        | Integrated circuit socket, 44 pin PLCC, through hole | 1
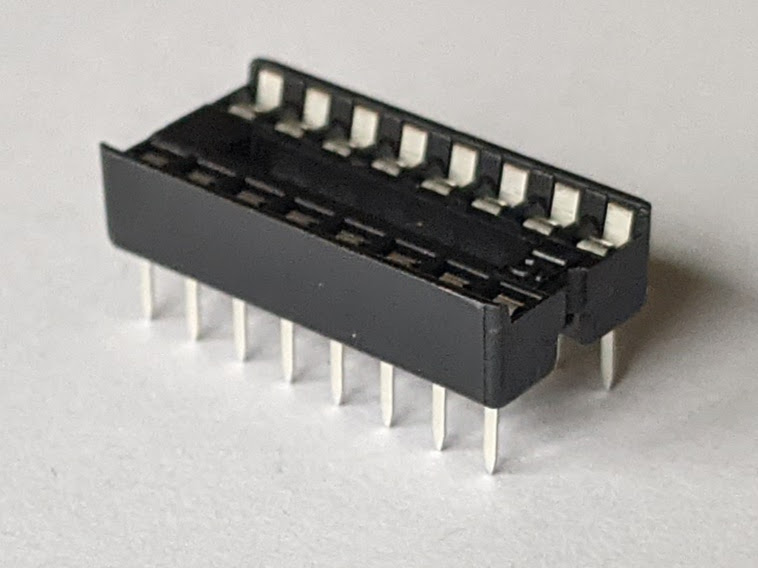
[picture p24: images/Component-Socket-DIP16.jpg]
IC Socket - DIP16
              | U5        | Integrated circuit socket, 16 pin DIP                | 1 (optional)
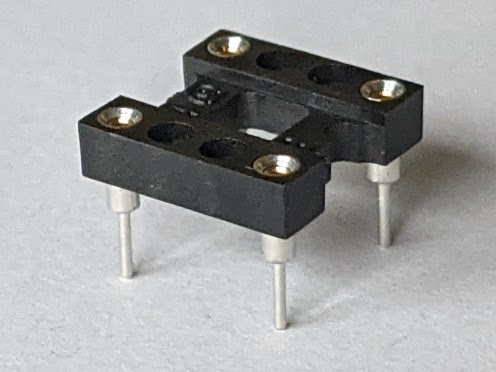
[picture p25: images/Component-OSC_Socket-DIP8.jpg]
Oscillator Socket - DIP8
    | X1        | 8 pin DIP, Half Can                                  | 1
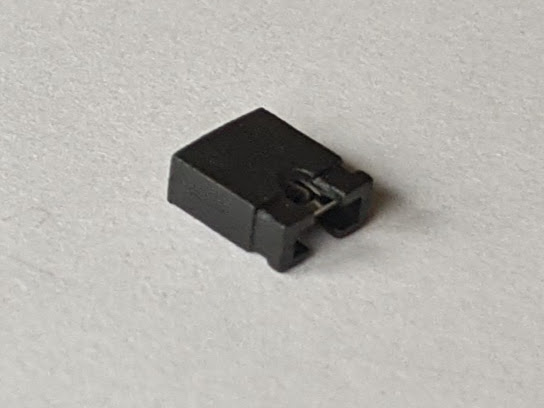
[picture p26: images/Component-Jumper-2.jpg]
Jumper
                             | J1        | Jumper/Shunt, 2 pin 2.54 mm pitch                    | 1 (optional)
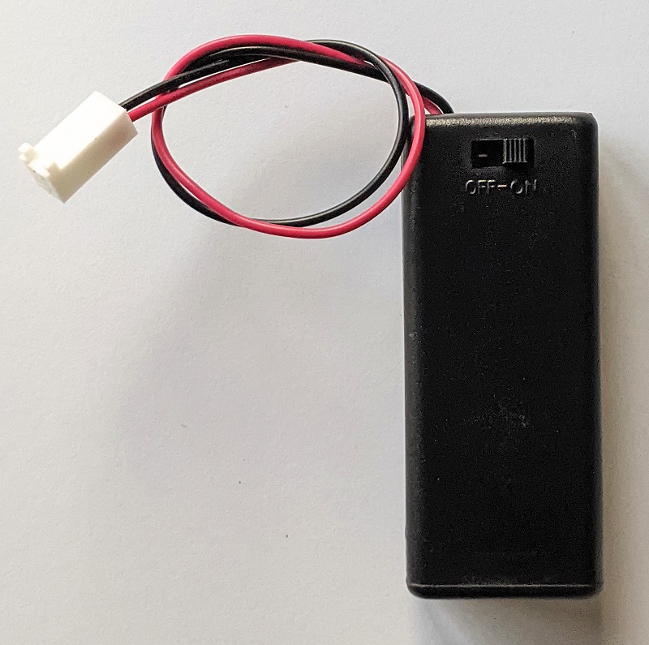
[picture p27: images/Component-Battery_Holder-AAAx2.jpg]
Battery Holder - AAAx2
 | J1        | 2xAAA battery enclosure with switch and connector    | 1 (optional)

## Assembly Steps

### 1. Gather supplies and parts

* Check that you have all the equipment and parts listed in the [Prerequisites](#prerequisites) section above
* Organize your workspace. If available, use ESD-safe surface and ESD strap when working on this project

### 2. Solder the components

Solder the components going from lower profile components to higher profile components, from smaller components to larger. Here is the recommended order:

* Solder RN1 and RN2 resistor arrays. Make sure that resistor arrays are oriented correctly. The first pin of the resistor array is marked with a printed dot, and the first pad on the board has a square shape

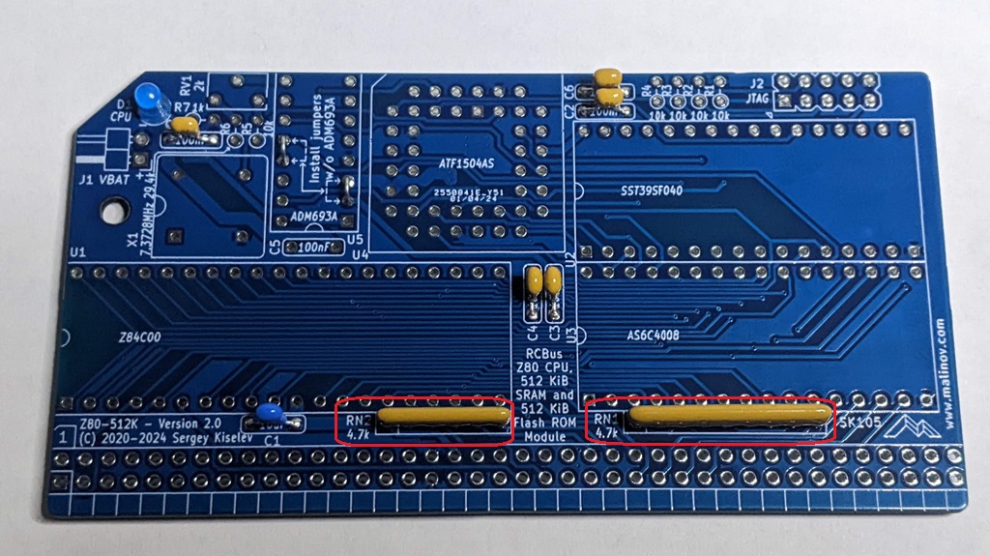
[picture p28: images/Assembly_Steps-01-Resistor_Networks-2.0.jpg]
Resistor networks


* Solder C1 10 uF and C2-C7 0.1 uF capacitors. Note that these are non-polarized ceramic capacitors, so they can be oriented either way. Trim the leads using cutters

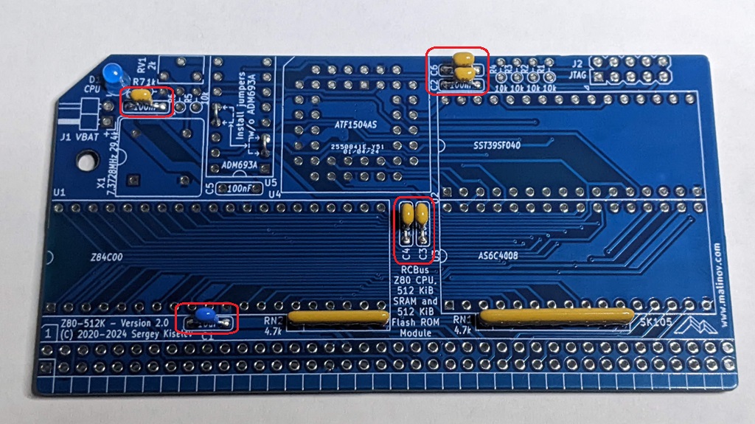
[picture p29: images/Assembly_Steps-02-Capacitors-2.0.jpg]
Capacitors


* If the U5 ADM693AZ CPU supervisor is not used (the kit’s default), install two wire jumpers in the U5 footprint as indicated on the board. Use cut capacitors' or resistors’ leads to make the jumpers.

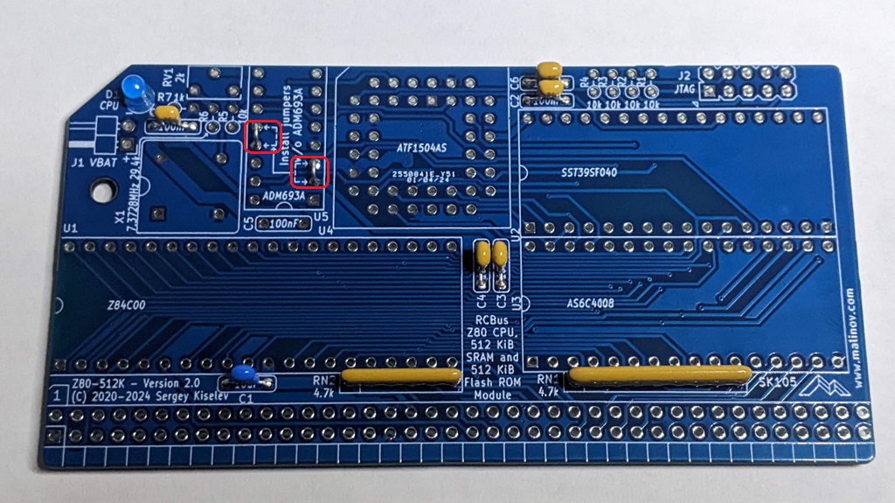
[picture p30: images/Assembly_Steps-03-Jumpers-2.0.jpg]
Wire jumpers


* Solder the D1 LED. Note that the LED is __polarized__. The square pad on the board correspond to the negative (cathode) lead of the LED. The negative lead on the LED is usually marked by an indent on otherwise round LED package, or by a shorter lead. If in doubt - use the multimeter (set to diode mode) to check the polarity
    
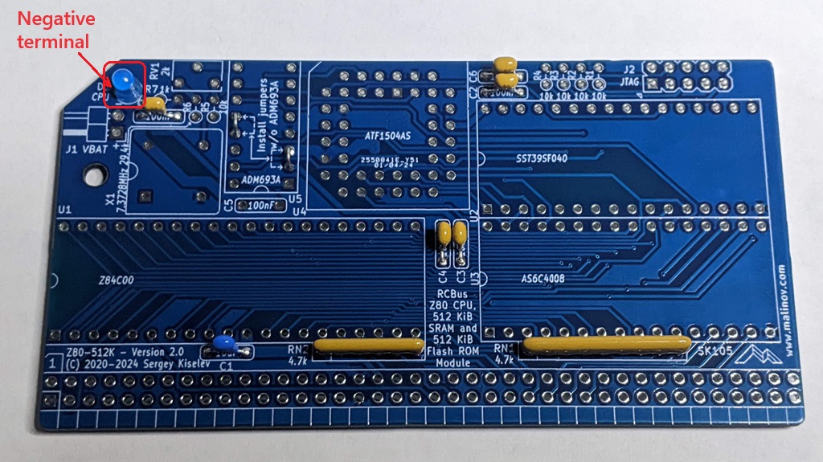
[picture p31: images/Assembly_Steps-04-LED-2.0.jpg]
LED


* Solder the sockets. Start with the X1 oscillator socket, continue with DIP integrated circuits' sockets, and finally solder PLCC44 socket.
  * Pay attention to the orientation of the sockets. The indents indicating pin 1, or the socket outline on the PCB's silk screen should match the socket orientation
  * If the U5 ADM693AZ CPU supervisor is used, also solder the U5 DIP-16 socket

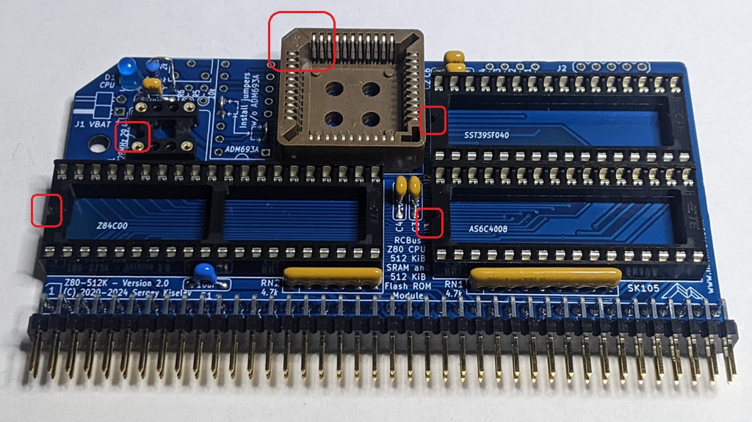
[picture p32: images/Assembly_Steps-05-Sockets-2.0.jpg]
Sockets


* Form the leads and solder the R7 resistor as shown on the picture below.
  * (Optional) If the U5 ADM693AZ CPU supervisor is used, also solder resistors R5 and R6.
  * (Optional) If the JTAG header is desired, also solder resistors R1-R4.
  * Resistor R7 is 1k with either 1% or %5 tolerance.
    * The 1k 1% resistor is marked with brown-black-black-brown-brown color code.
    * The 1k 5% resistor is marked with brown-black-red-gold color code.
  * Resistor R5 is 10k with 1% tolerance. It is marked with brown-black-black-red-brown color code.
  * Resistor R6 is 29.4k with 1% tolerance. It is marked with red-white-yellow-red-brown color code.
  * Resistors R1-R4 are 10k with either 1% or 5% tolerance.
    * 10k 1% resistors are marked with brown-black-black-red-brown color code.
    * 10k 5% resistors are marked with brown-black-orange-gold color code.
  * The resistors are not polarized and can be oriented either way. Trim the leads using cutters.

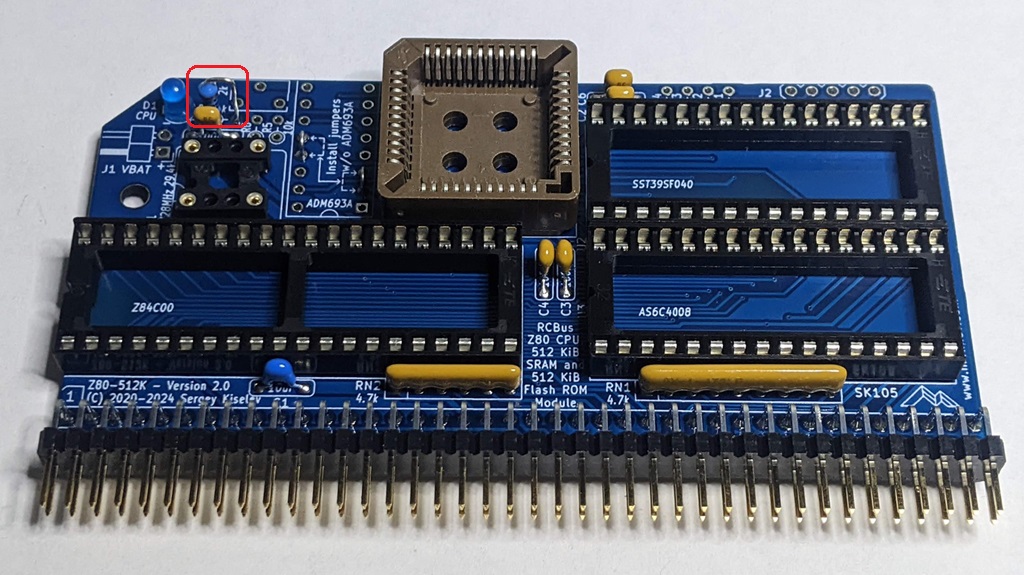
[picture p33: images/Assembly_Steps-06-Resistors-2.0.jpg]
Resistors


* Solder RCBus header J3

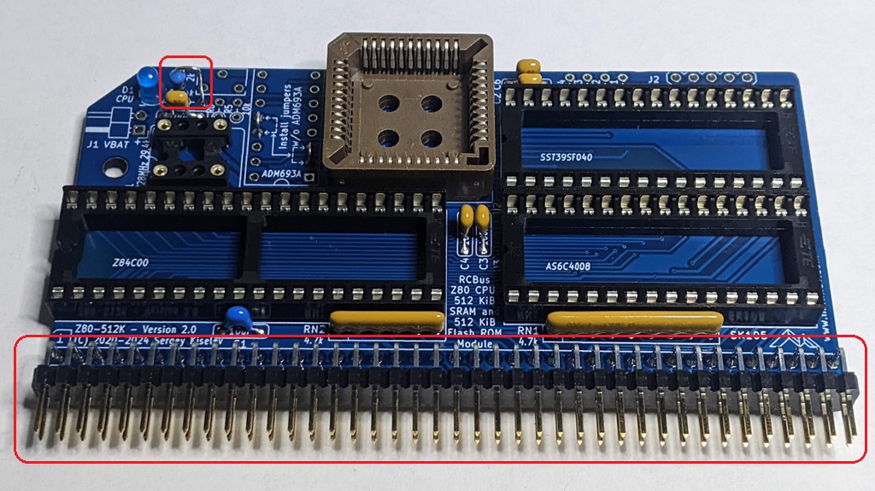
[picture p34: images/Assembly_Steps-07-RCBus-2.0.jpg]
RCBus Header


* (Optional) If the U5 ADM693AZ CPU supervisor is used, solder trimmer resistor RV1. Trim the leads using cutters

*Note:* The Z80-512K can generate NMI interrupts to the CPU when power failure is detected. The RV1 trimmer resistor is used to fine tune the power failure threshold voltage. It is normally safe to set it to a middle position. If using the NMI on power failure feature, the RV1 can be adjusted by setting the board power supply to the desired power failure voltage (for example, 4.5 V), and adjusting the resistor until the /PFO output (pin 10) of U5 goes low.

* (Optional) If the U5 ADM693AZ CPU supervisor is used, solder J1 battery connector. Pay attention to the orientation of this connector. The connector latch should match the drawing on the PCB's silk screen.
  
* (Optional) If the JTAG header is desired, for example, if you plan to use JTAG to re-program the CPLD, solder J2 2x5 header

### 3. Check your soldering work

* Make sure all pins of all components are soldered properly
* If desired, clean the flux using isopropyl alcohol, cotton swabs. You might want to scrub the board lightly with a used toothbrush to remove the flux

### 4. Insert the integrated circuits to the sockets
* Prior to inserting DIP integrated circuits to the sockets board, bend their leads slightly, so they point 90 degrees downward. Put the IC on the side and gently push it down to bend the leads. Repeat on the other side of the IC
* Double check that you're placing the integrated circuit in the right socket, check the IC orientation. The index notch on the IC should match the notch on the socket and the drawing on the PCB's silkscreen
* To insert the ATF1504AS CPLD integrated circuit in PLCC44 package, place it on the top of the socket, double check the orientation of the integrated circuit, and firmly push it down. It should click into the socket

Assembled board

### 5. Place a jumper over J1 or connect a battery

This step is optional, and required only if the U5 ADM693AZ CPU supervisor is used.

* If SRAM battery backup is not needed, place a jumper on J1 connector
* If SRAM battery is desired, install two AAA batteries in the battery holder, and connect battery holder to J1 connector
* **Important**: Do not leave J1 unconnected. The board might not boot if J1 is left floating

### 6. Test the module
  * Plug the module into an RCBus compatible backplane
  * Plug a supported serial module, such as Steve Cousins' [SC716 – RCBus Z80 SIO/2 Serial Module](https://smallcomputercentral.com/sc716-rcbus-z80-sio-2-serial-module/), [SC725 – RCBus Serial and Timer Module](https://smallcomputercentral.com/sc725-rcbus-serial-and-timer-module/), or [SC705 – RCBus Serial ACIA Module](https://smallcomputercentral.com/sc705-rcbus-serial-acia/). If using the [SC716](https://smallcomputercentral.com/sc716-rcbus-z80-sio-2-serial-module/) module, set the address to 0x80 using JP1, and set JP1 and JP2 to 1-2 position, if you would like to use the Z80-512K clock generator for the SIO bitrate.
  * Double check that the modules are installed in the correct orientation, and pin 1 on the modules match that of the backplane.
  * Connect the serial console cable, such as FTDI USB to RS232 to the serial module. Launch terminal emulation software, and configure it for 115200bps, 8-bit, no parity, one stop bit operation.
  * Apply the power. The indicator LED on the Z80-512K module should blink briefly, and then light up. The RomWBW prompt should appear on the terminal.

__Congratulations! Enjoy your Z80-512K Module!__

A CP/M computer system consisting of [Z80-512K module](https://github.com/skiselev/Z80-512K), [Flock V2 Floppy Disk Controller and Real Time Clock module](https://github.com/skiselev/flock-v2), [SC725 – RCBus Serial and Timer Module](https://smallcomputercentral.com/sc725-rcbus-serial-and-timer-module/), and [SC701 – RCBUS Backplane](https://smallcomputercentral.com/sc701-rcbus-backplane/):

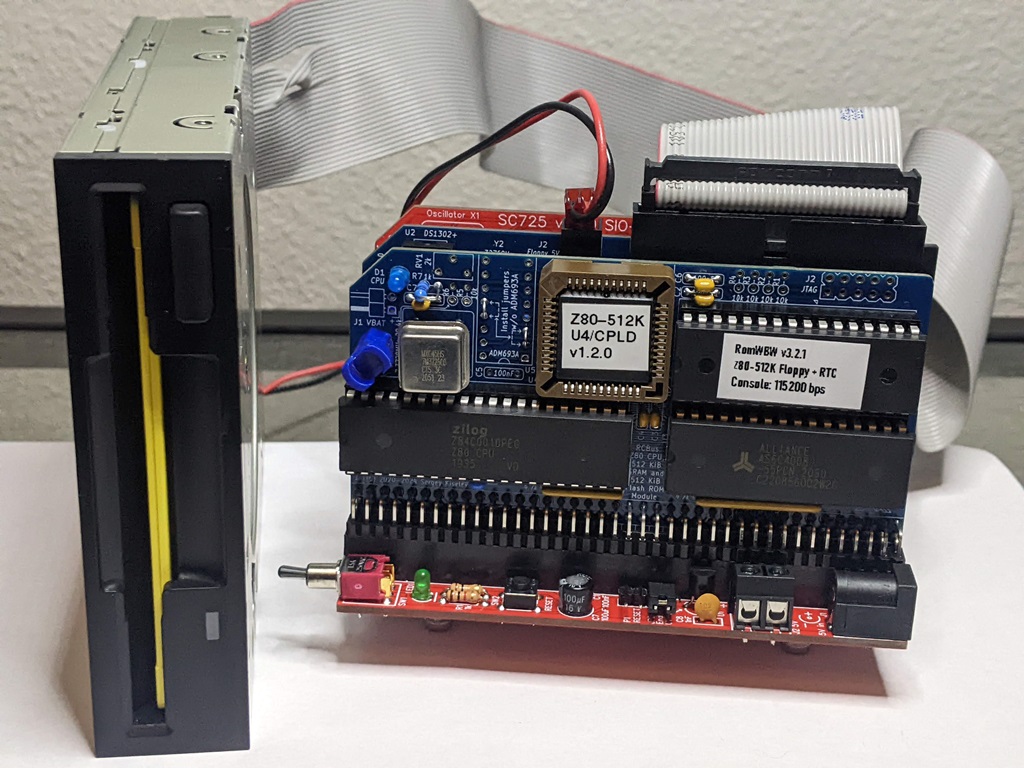
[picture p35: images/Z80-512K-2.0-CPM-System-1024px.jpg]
Z80-512K - Complete Computer with Serial and Floppy


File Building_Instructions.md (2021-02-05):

# Z80-512K - Building Instructions

## Prerequisites

### Tools, Equipment, and Supplies

* Soldering iron with a fine tip. Temperature controlled soldering station is recommended
* Needle nose pliers for forming components' leads
* Small side cutters for cutting components' leads
* Universal programmer capable of programming SST39F040 Flash ROM ICs. For example, MiniPro TL866CS or MiniPro TL866A
* Multimeter with frequency measurement, an oscilloscope, or a logic analyzer can be beneficial for troubleshooting
* Desk lamp, magnifying glass
* Solder suitable for soldering electronics. For example: rosin core Sn63/Pb37, Sn60/Pb40, or a lead-free solder such as Sn96.5/Ag3.0/Cu0.5 (sometimes referred to as SAC305)
* Solder wick for removing excess of solder
* 99% Isopropyl Alcohol for removing the excess of flux after soldering
* Lint free wipes, used toothbrush, cotton swabs for cleaning the PCB before and after soldering

### Parts

The table below shows the images of the components included in the kit. The up to date list of parts provided in the [Bill of Materials](README.md#bill-of-materials) section of the [README.md](README.md) file. It also provides the recommended sources for the parts.

Image                                                         | Reference | Description                                         | Quantity
------------------------------------------------------------- | --------- | --------------------------------------------------- | --------
PCB - Z80-512K v1.2 | PCB       | Z80-512K PCB - Version 1.2                          | 1
CPU - Z84C0010PEG        | U1        | Z84C0010PEG - Z80 CPU, CMOS, 40 pin DIP             | 1
Flash ROM - SST39SF040    | U2        | SST39SF040 - 512 KiB Flash ROM, 32 pin DIP          | 1
SRAM - AS6C4008             | U3        | AS6C4008 - 512 KiB SRAM, 32 pin DIP                 | 1
CPLD - ATF1504AS           | U4        | ATF1504AS - CPLD, 64 macrocells, 44 pin PLCC        | 1
CPU Supervisor - ADM693A     | U5        | ADM693A - Microprocessor Supervisory Circuit        | 1
Oscillator - 7.3728 MHz          | X1        | 7.3728 MHz, CMOS oscillator, half can               | 1
LED - 3mm - Blue            | D1        | LED indicator, 3 mm, blue                           | 1
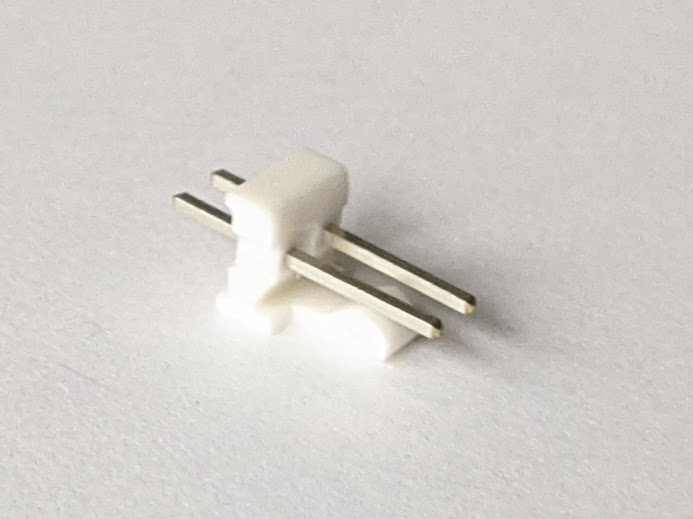
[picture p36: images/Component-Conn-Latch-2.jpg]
Friction Lock Connector
 | J1        | 2 pin header with friction lock                     | 1
Pin Header 2x5            | J2        | 2x5 pin header, 2.54 mm pitch, vertical             | 1
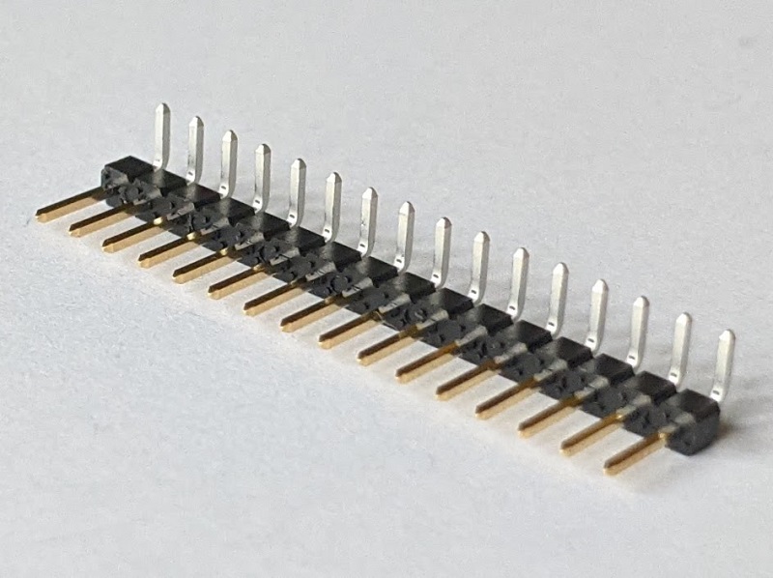
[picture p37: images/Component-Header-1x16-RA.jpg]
Pin Header 1x16 Right
 | J3        | 1x16 pin header, 2.54 mm pitch, right angle         | 2
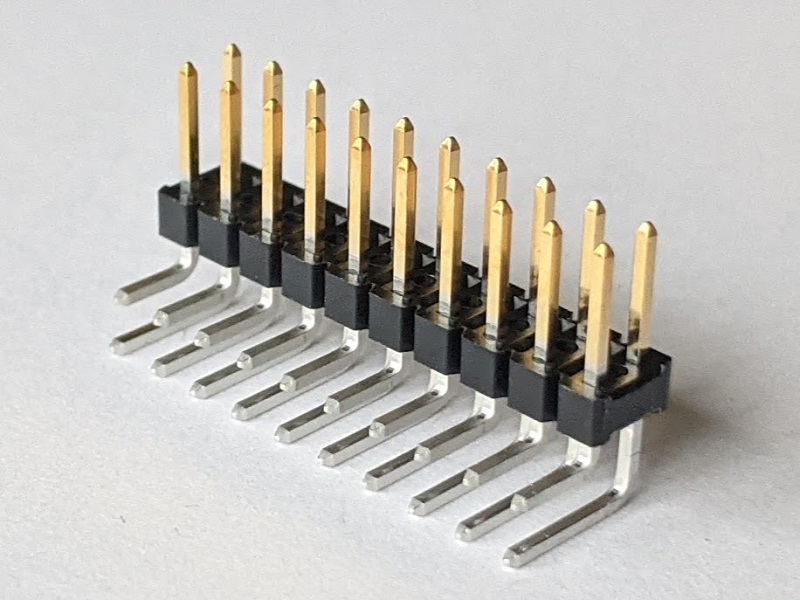
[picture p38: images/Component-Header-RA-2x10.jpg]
Pin Header 2x10 Right
 | J3, J4    | 2x10 pin header, 2.54 mm pitch, right angle         | 1
Ceramic Capacitors - 0.1uF | C1 - C7   | Capacitor, 0.1 uF, 50V, MLCC, 5 mm pitch            | 7
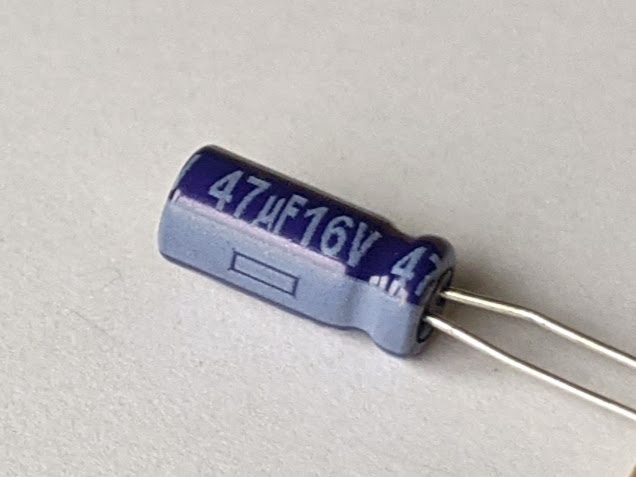
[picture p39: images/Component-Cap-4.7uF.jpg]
Electrolytic Capacitor - 4.7uF
 | C7    | Capacitor, 47 uF, 25V, Electrolytic, 5 mm diameter, 2 mm pitch | 1
Resistor Network - 8x4.7k   | RN1       | Resistor Network, 4.7 kohm, bussed, 9 pin SIP       | 1
Resistor Network - 5x4.7k   | RN2       | Resistor Network, 4.7 kohm, bussed, 6 pin SIP       | 1
Resistor - 10k               | R1 - R5   | Resistor, 10 kohm, 0.25 W, 1% tolerance, axial      | 5
Resistor - 29.4k           | R6        | Resistor, 29.4 kohm, 0.25 W, 1% tolerance, axial    | 1
Resistor - 1k                 | R7        | Resistor, 1 kohm, 0.25 W, axial                     | 1
Trimmer Resistor - 2k       | RV1       | Trimmer Resistor, 2 kohm, through hole              | 1
IC Socket - DIP40       | U1        | Intergrated circuit socket, 40 pin DIP              | 1
IC Socket - DIP32       | U2, U3    | Intergrated circuit socket, 32 pin DIP              | 2
IC Socket - PLCC44     | U4        | Intergrated circuit socket, 44 pin PLCC, through hole | 1
IC Socket - DIP16       | U5        | Intergrated circuit socket, 16 pin DIP              | 1
Oscillator Socket - DIP8 | X1    | 8 pin DIP, Half Can                                 | 1
Jumper                      | J1        | Jumper/Shunt, 2 pin 2.54 mm pitch                   | 1
Battery Holder - AAAx2 | J1 | 2xAAA battery enclosure with switch and connector   | 1 (Optional)

## Assembly Steps

1. Gather supplies and parts
  * Check that you have all the equipment and parts listed in the [Prerequisites](prerequisites) section above
  * Organize your workspace. If available, use ESD-safe surface and ESD strap when working on this project
2. Solder the components going from lower profile components to higher profile components, from smaller components to larger. Here is the recommended order:
  * Solder RN1 and RN2 resistor arrays
![Resistor Networks](images/Assembly_Steps-Resistor_Network.jpg]
  * Solder C1-C7 0.1 uF capacitors. Note that these are non-polarized ceramic capacitors, so they can be oriented either way. Trim the leads using cutters
![0.1 uF Capactiors](images/Assembly_Steps-Capacitors-100nF.jpg]
  * Solder the D1 LED
    * Note that the LED is __polarized__. The square pad on the board correspond to the negative (cathode) lead of the LED. The negative lead on the LED is usually marked by an indent on otherwise round LED package, or by a shorter lead. If in doubt - use the multimeter (set to diode mode) to check the polarity
  * Solder the sockets. Start with the X1 oscillator socket, continue with DIP integrated circuits' sockets, and finally solder PLCC44 socket.
    * Pay attention to the orientation of the sockets. The indents indicating pin 1, or the socket outline on the PCB's silk screen should match the socket orientation
  * Form leads and solder R7, R5, and R6 resistors as shown on the picture below. If you plan to use JTAG to re-program the CPLD, also solder resistors R1-R4.
    * Resistor R7 is 1k with 5% tolerance. It is market with brown-black-red-gold color code
    * Resistor R5 is 10k with 1% tolerance. It is market with brown-black-black-red-brown color code
    * Resistor R6 is 29.4k with 1% tolerance. It is market with red-white-yellow-red-brown color code
    * Resistors R1-R4 are 10k with either 1% tolerance, marked with brown-black-black-red-brown color code, or with 5% tolerance, marked with brown-black-orange-gold color code
    * The resistors are not polarized and can be oriented either way. Trim the leads using cutters
  * Solder trimmer resistor RV1. Trim the leads using cutters
  * Solder J1 connector. Pay attention to the orientation of this connector. The connector latch should match the drawing on the PCB's silk screen. Refer to the picture below of the correct orientation
  * Solder C8 capacitor. Note that this is a __polarized__ electrolytic capacitor and it needs to be oriented properly. Make sure that the negative lead of the capacitor (marked on the package) matches the white colored area on the PCB.
  * Solder RC2014* headers (J3 and J4):
    * If two 1x16 and one 2x10 headers are used, cut 3 pins from one of the 1x16 headers to make a 1x13 header. Solder 2x10 header first, making sure that its pins are parallel to the baord. Next solder 1x16 and 1x13 headers, making sure that they align properly with 2x10 header, and the pins form one nice straight line.
    * If 2x40 header used, using pliers gently remove extra pins - 16 pins from upper row on the left side (connector pins facing toward you), 14 pins from upper row on the right side, and one pin from the lower row on the right side. Refer to the picture below
  * If you plan to use JTAG to re-program the CPLD, solder J2 2x5 header
3. Check your soldering work. Make sure all pins of all components are soldered properly. If desired, clean the flux using isopropyl alcohol, cotton swabs. You might want to scrub the board lightly with a used toothbrush to remove the flux
4. Insert the integrated circuts to the sockets
  * Prior to insering DIP integrated circuits to the sockets board, bend their leads slightly, so they point 90 degrees downward. Put the IC on the side and gently push it down to bend the leads. Repeat on the other side of the IC
  * Double check that you're placing the integrated circuit in the right socket, check the IC orientation. The index notch on the IC should match the notch on the socket and the drawing on the PCB's silkscreen
  * To insert the ATF1504AS CPLD integrated circuit in PLCC44 package, place it on the top of the socket, double check the orientation of the integrated circuit, and firmly push it down
5. Test the module
  * Plug the module into an RC2014* compatible backplane
  * Plug a supported serial module, such as Z80 SIO or MC68B50 ACIA. If using Steve Cousins' [SC104](https://smallcomputercentral.wordpress.com/sc104-z80-sio-2-module-rc2014/) module, make sure it is configured in "Compatibility Mode" and the address is set to 0x80
  * Double check that the modules are installed in the correct orientation, and pin 1 on the modules match that of the backplane.
  * Connect the serial console cable, such as FTDI USB to RS232 to the serial module. Launch terminal emulation software, and configure it for 115200bps, 8-bit, no parity, one stop bit operation.
  * Apply the power. The indicator LED on the Z80-512K module should blink briefly, and then light up. The RomWBW prompt should appear on the terminal.

__Congratulations! Enjoy your Z80-512K Module!__

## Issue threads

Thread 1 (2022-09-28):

RV1 is not well described.I have not found a description of its purpose, nor of the method to determine correct setting.

riwide, 2022-09-28:
It would help understand and diagnose, to know more about RV1.
Why is it needed and how should I set its value?

I have parts and PCB on order to construct an Z80-512K board.

skiselev, 2022-09-29:
I've added the following note to the [Assembly Instructions](https://github.com/skiselev/Z80-512K/blob/main/Assembly_Instructions.md):

*Note:* The Z80-512K can generate NMI interrupts to the CPU when power failure is detected. The RV1 trimmer resistor is used to fine tune the power failure threshold voltage. It is normally safe to set it to a middle position. If using the NMI on power failure feature, the RV1 can be adjusted by setting the board power supply to the desired power failure voltage (for example, 4.5 V), and adjusting the resistor until the /PFO output (pin 10) of U5 goes low.

Let me know if you think it sufficiently clarifies the purpose of RV1

riwide, 2022-09-29:
Thanks, makes sense now. I will know more once I have it built and running.

Cheers

Richard

On Thu, 29 Sept 2022, 01:17 Sergey Kiselev, ***@***.***>
wrote:

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

Closed 2024-01-04.

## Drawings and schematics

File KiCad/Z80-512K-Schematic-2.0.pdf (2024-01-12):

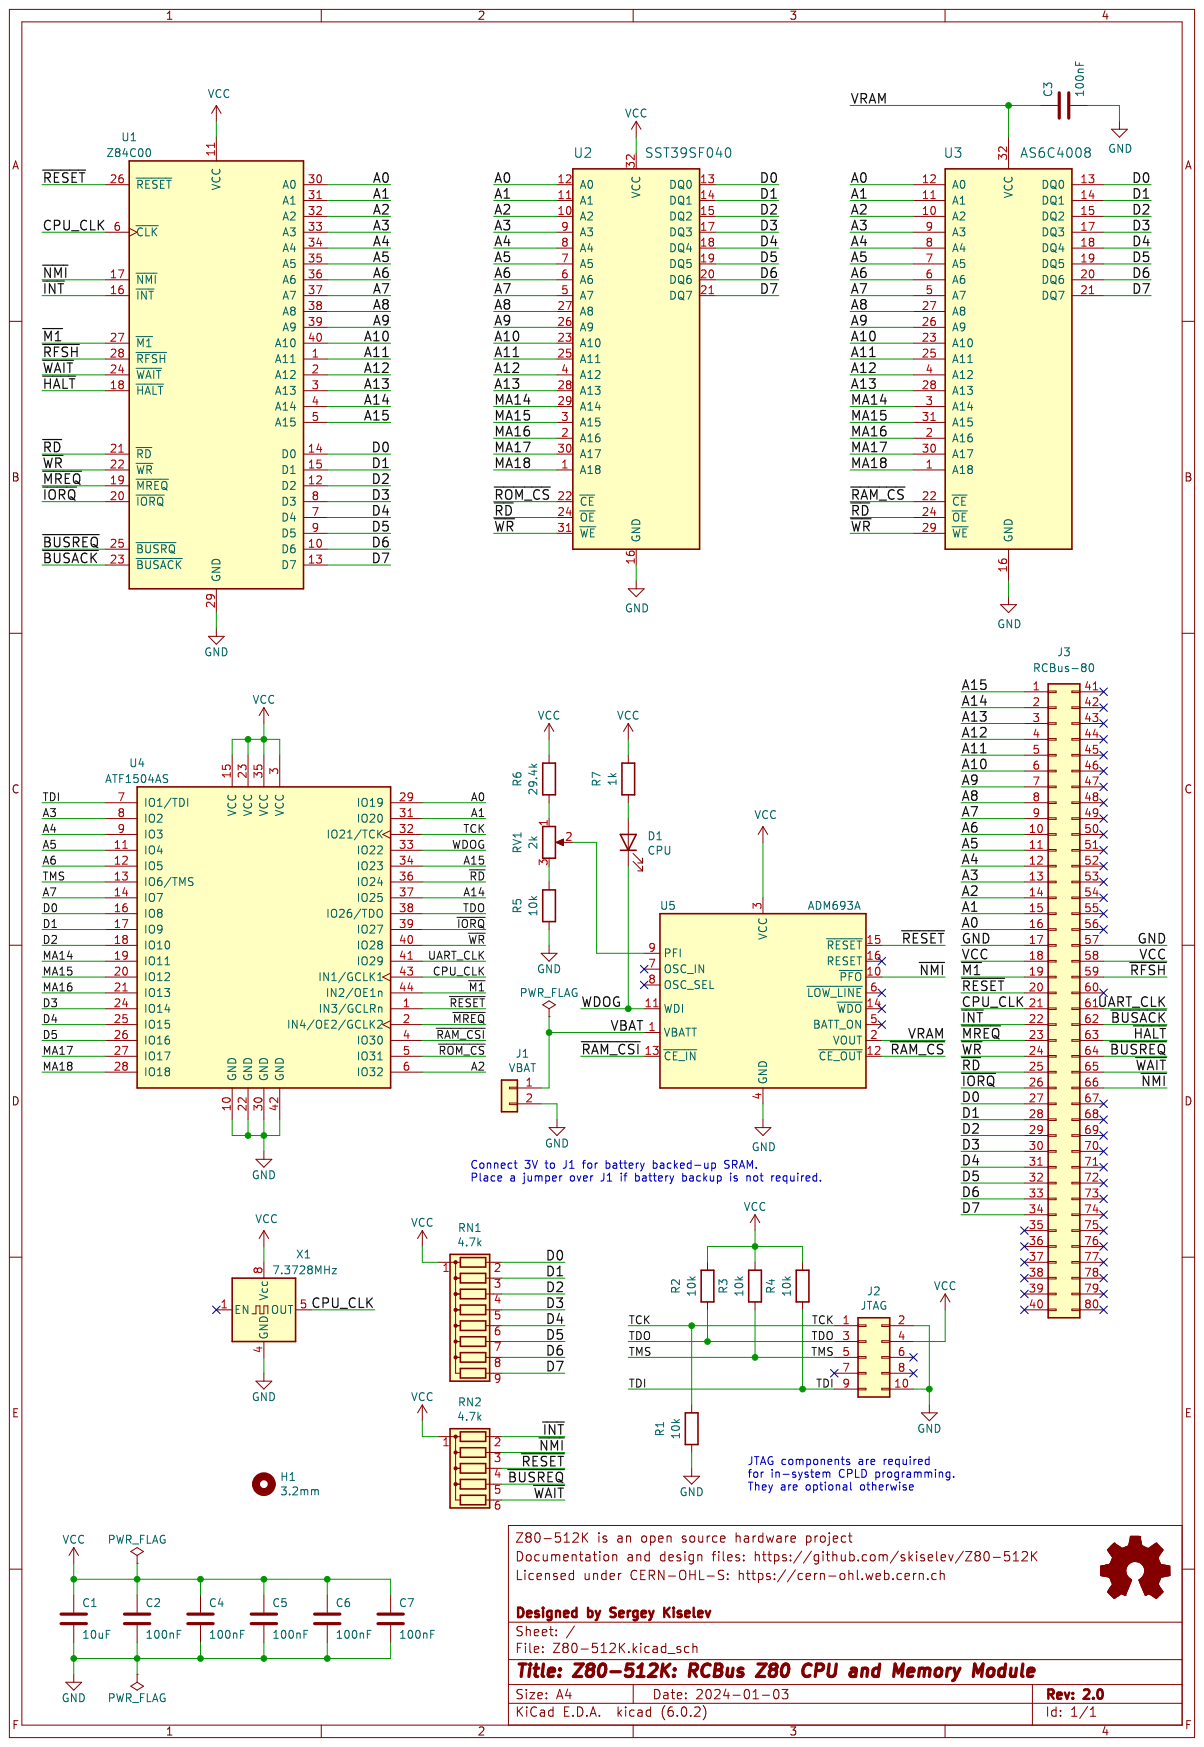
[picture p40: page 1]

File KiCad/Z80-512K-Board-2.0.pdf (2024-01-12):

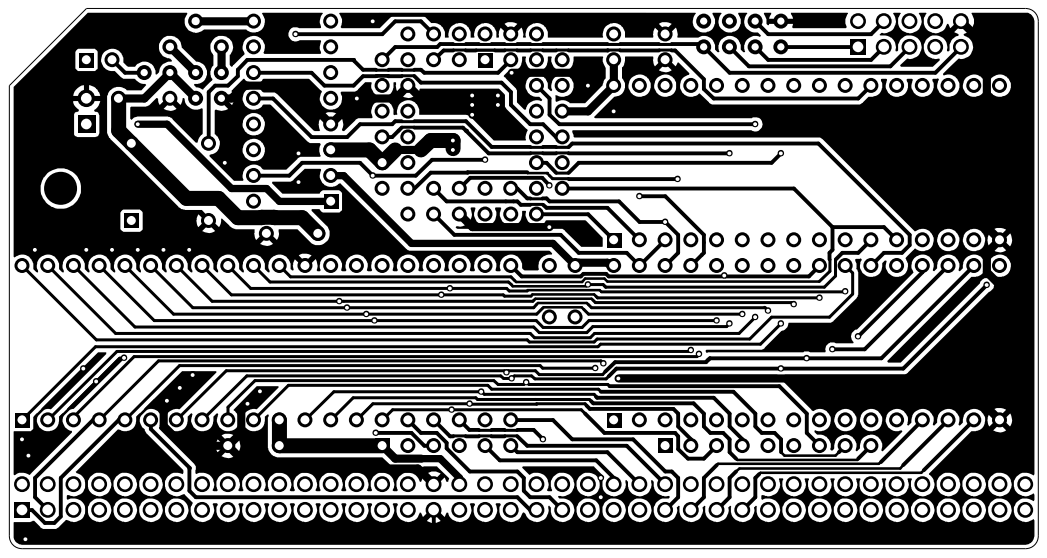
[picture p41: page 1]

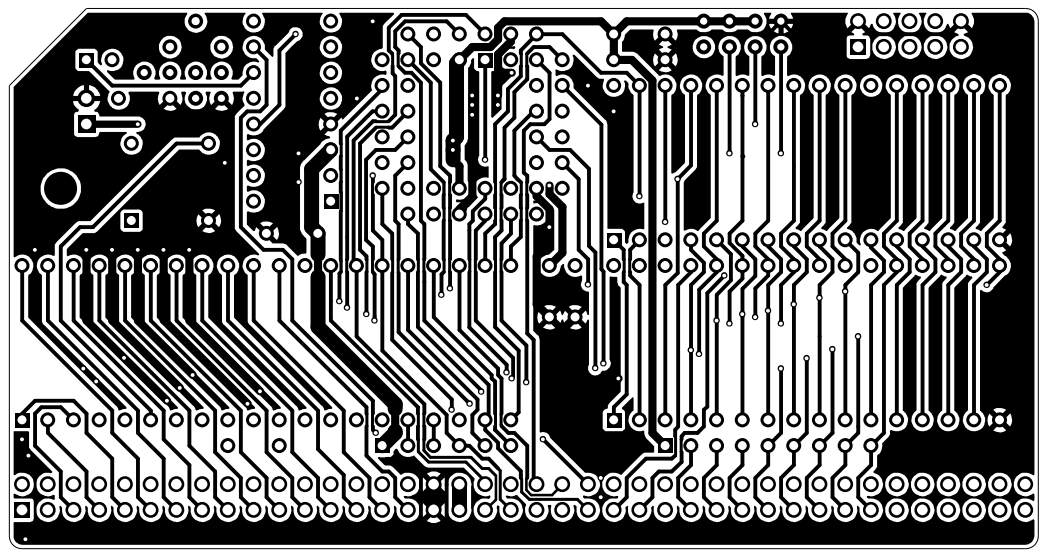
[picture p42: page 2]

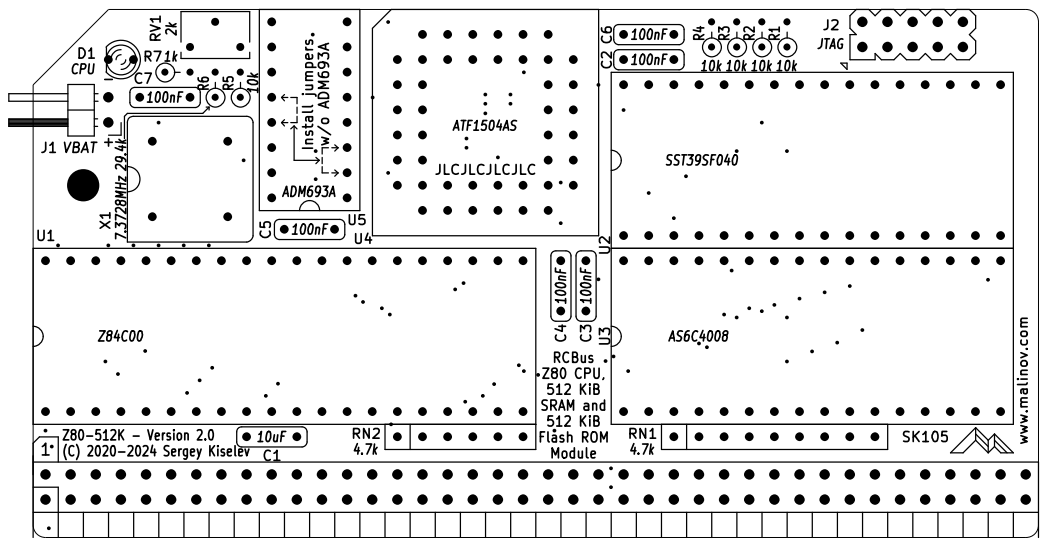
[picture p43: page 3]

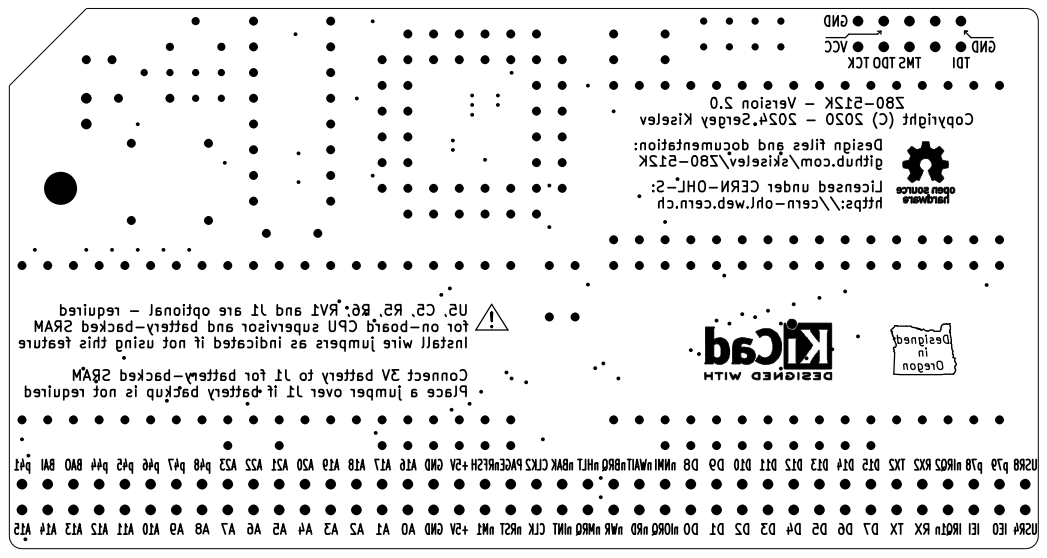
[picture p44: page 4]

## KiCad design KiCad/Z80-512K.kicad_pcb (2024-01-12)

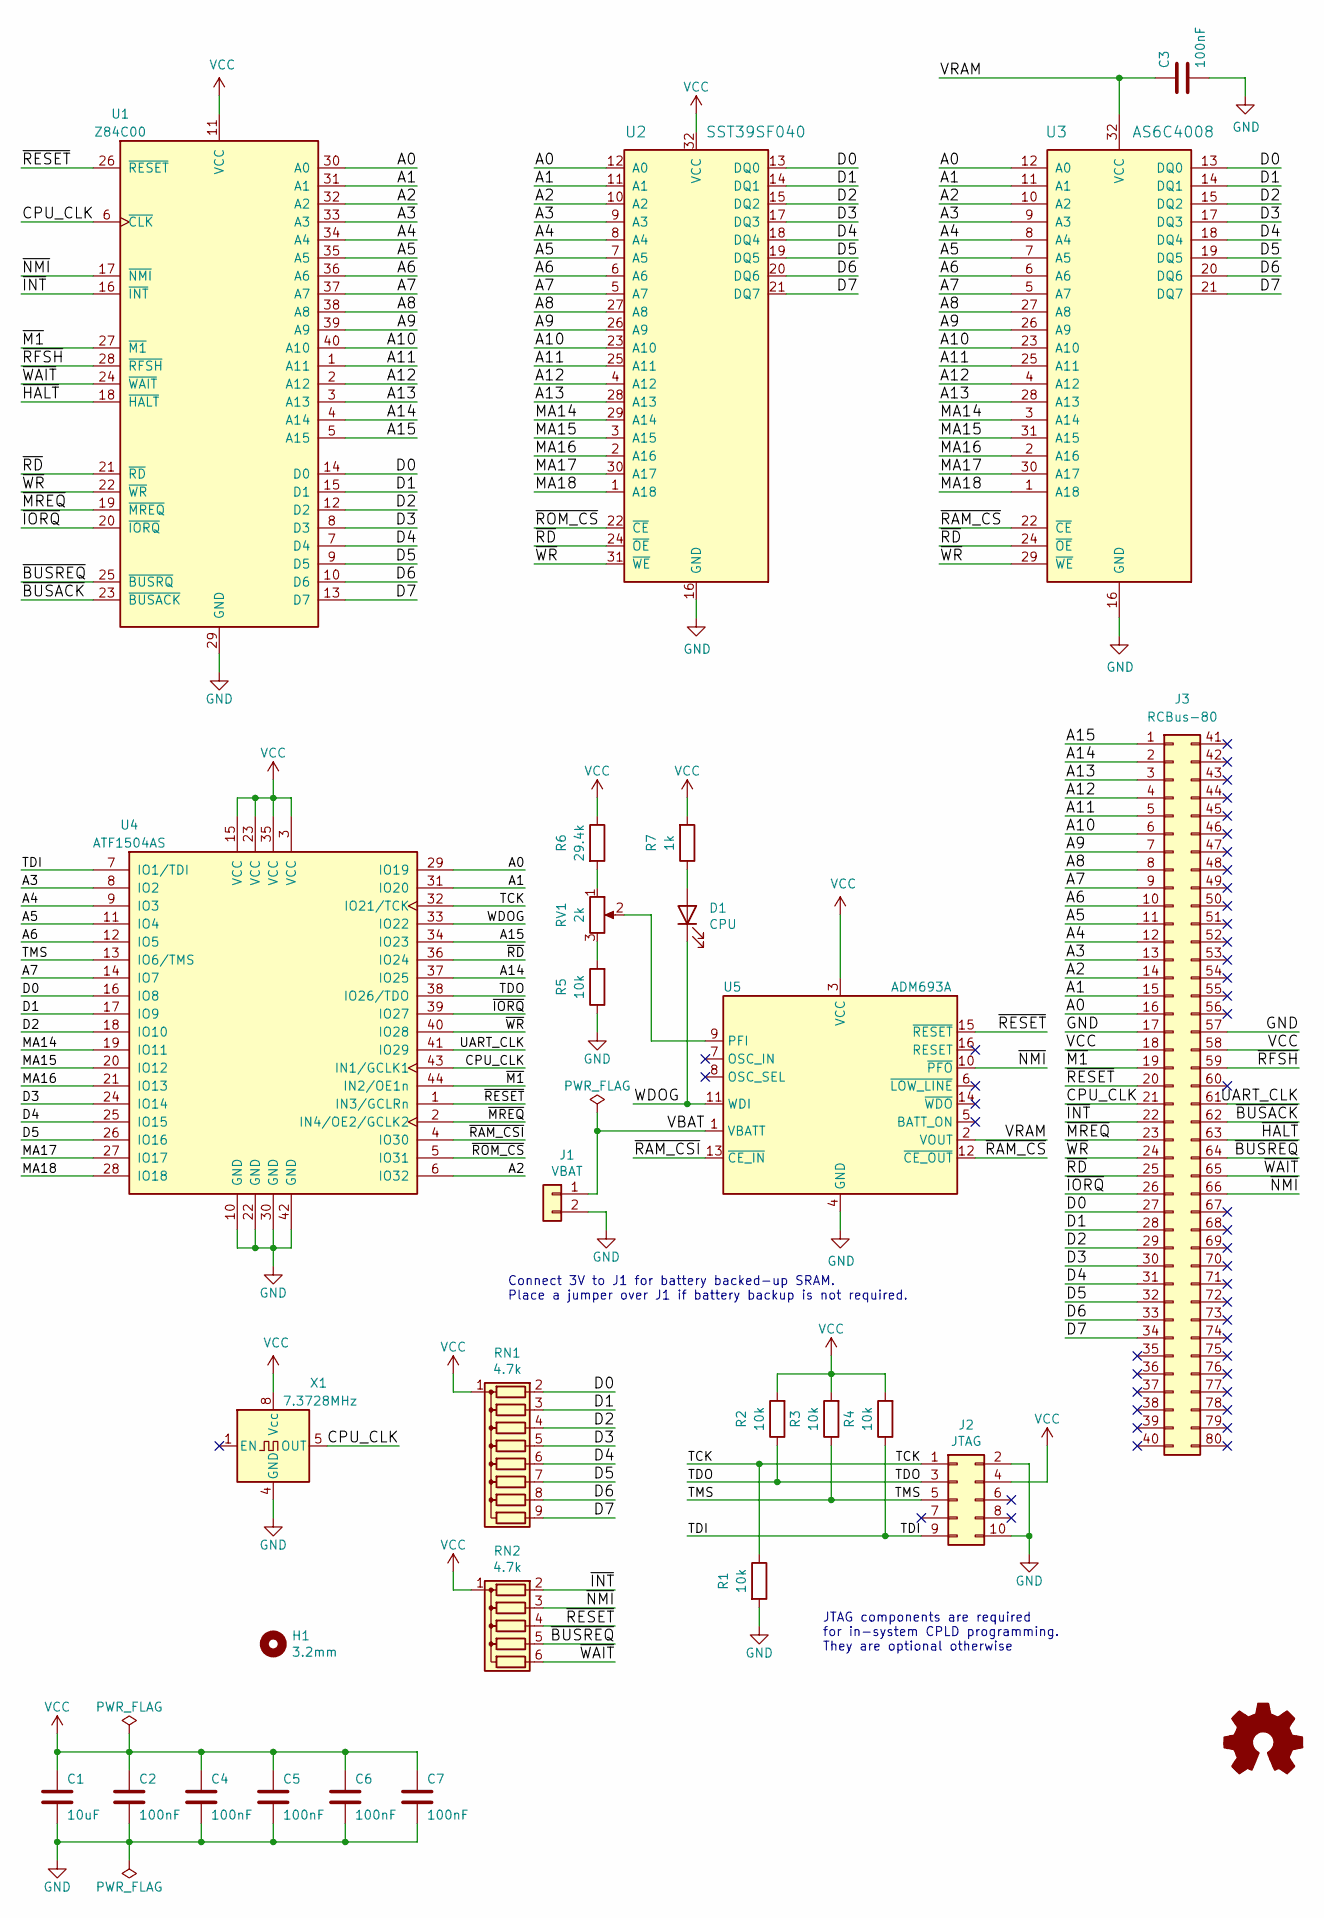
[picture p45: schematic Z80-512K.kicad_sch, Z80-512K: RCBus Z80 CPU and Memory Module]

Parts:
C1: 10uF; Cap_Cer_508
C2, C3, C4, C5, C6, C7: 100nF; Cap_Cer_508
D1: CPU; LED_3mm
H1: 3.2mm; MountingHole_3.2mm_M3_DIN965
J1: VBAT; PinHeader_1x02_P2.54mm_Horizontal
J2: JTAG; Conn_Pin_Header_5x2_2.54mm
J3: RCBus-80; Conn_Pin_Header_40x2_2.54mm_Right_Angle_RCBus80
LOGO1: Logo_Open_Hardware_Small; OSHW-Logo_5.7x6mm_SilkScreen
R1, R2, R3, R4, R5: 10k; R_Axial_DIN0204_L3.6mm_D1.6mm_P2.54mm_Vertical
R6: 29.4k; R_Axial_DIN0204_L3.6mm_D1.6mm_P2.54mm_Vertical
R7: 1k; R_Axial_DIN0204_L3.6mm_D1.6mm_P2.54mm_Vertical
RN1: 4.7k; Conn_SIL9
RN2: 4.7k; Conn_SIL6
RV1: 2k; Potentiometer_Bourns_3266W_Vertical
U1: Z84C00; Socket_DIP40_600
U2: SST39SF040; Socket_DIP32_600
U3: AS6C4008; Socket_DIP32_600
U4: ATF1504AS; IC_PLCC44_TH
U5: ADM693A; Socket_DIP16_300
X1: 7.3728MHz; OSC_Half_Can_DIP8

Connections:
/A0: J3.16, U1.30 (A0), U2.12 (A0), U3.12 (A0), U4.29 (IO19)
/A1: J3.15, U1.31 (A1), U2.11 (A1), U3.11 (A1), U4.31 (IO20)
/A2: J3.14, U1.32 (A2), U2.10 (A2), U3.10 (A2), U4.6 (IO32)
/A3: J3.13, U1.33 (A3), U2.9 (A3), U3.9 (A3), U4.8 (IO2)
/A4: J3.12, U1.34 (A4), U2.8 (A4), U3.8 (A4), U4.9 (IO3)
/A5: J3.11, U1.35 (A5), U2.7 (A5), U3.7 (A5), U4.11 (IO4)
/A6: J3.10, U1.36 (A6), U2.6 (A6), U3.6 (A6), U4.12 (IO5)
/A7: J3.9, U1.37 (A7), U2.5 (A7), U3.5 (A7), U4.14 (IO7)
/A8: J3.8, U1.38 (A8), U2.27 (A8), U3.27 (A8)
/A9: J3.7, U1.39 (A9), U2.26 (A9), U3.26 (A9)
/A10: J3.6, U1.40 (A10), U2.23 (A10), U3.23 (A10)
/A11: J3.5, U1.1 (A11), U2.25 (A11), U3.25 (A11)
/A12: J3.4, U1.2 (A12), U2.4 (A12), U3.4 (A12)
/A13: J3.3, U1.3 (A13), U2.28 (A13), U3.28 (A13)
/A14: J3.2, U1.4 (A14), U4.37 (IO25)
/A15: J3.1, U1.5 (A15), U4.34 (IO23)
/CPU_CLK: J3.21, U1.6 (~CLK), U4.43 (IN1/GCLK1), X1.5 (OUT)
/D0: J3.27, RN1.2 (R1), U1.14 (D0), U2.13 (DQ0), U3.13 (DQ0), U4.16 (IO8)
/D1: J3.28, RN1.3 (R2), U1.15 (D1), U2.14 (DQ1), U3.14 (DQ1), U4.17 (IO9)
/D2: J3.29, RN1.4 (R3), U1.12 (D2), U2.15 (DQ2), U3.15 (DQ2), U4.18 (IO10)
/D3: J3.30, RN1.5 (R4), U1.8 (D3), U2.17 (DQ3), U3.17 (DQ3), U4.24 (IO14)
/D4: J3.31, RN1.6 (R5), U1.7 (D4), U2.18 (DQ4), U3.18 (DQ4), U4.25 (IO15)
/D5: J3.32, RN1.7 (R6), U1.9 (D5), U2.19 (DQ5), U3.19 (DQ5), U4.26 (IO16)
/D6: J3.33, RN1.8 (R7), U1.10 (D6), U2.20 (DQ6), U3.20 (DQ6)
/D7: J3.34, RN1.9 (R8), U1.13 (D7), U2.21 (DQ7), U3.21 (DQ7)
/MA14: U2.29 (A14), U3.3 (A14), U4.19 (IO11)
/MA15: U2.3 (A15), U3.31 (A15), U4.20 (IO12)
/MA16: U2.2 (A16), U3.2 (A16), U4.21 (IO13)
/MA17: U2.30 (A17), U3.30 (A17), U4.27 (IO17)
/MA18: U2.1 (A18), U3.1 (A18), U4.28 (IO18)
/TCK: J2.1, R1.1, U4.32 (IO21/TCK)
/TDI: J2.9, R4.1, U4.7 (IO1/TDI)
/TDO: J2.3, R2.1, U4.38 (IO26/TDO)
/TMS: J2.5, R3.1, U4.13 (IO6/TMS)
/UART_CLK: J3.61, U4.41 (IO29)
/VBAT: J1.1, U5.1 (VBATT)
/VRAM: C3.2, U3.32 (VCC), U5.2 (VOUT)
/WDOG: D1.1 (K), U4.33 (IO22), U5.11 (WDI)
/~BUSACK: J3.62, U1.23 (~BUSACK)
/~BUSREQ: J3.64, RN2.5 (R4), U1.25 (~BUSRQ)
/~HALT: J3.63, U1.18 (~HALT)
/~INT: J3.22, RN2.2 (R1), U1.16 (~INT)
/~IORQ: J3.26, U1.20 (~IORQ), U4.39 (IO27)
/~M1: J3.19, U1.27 (~M1), U4.44 (IN2/OE1n)
/~MREQ: J3.23, U1.19 (~MREQ), U4.2 (IN4/OE2/GCLK2)
/~NMI: J3.66, RN2.3 (R2), U1.17 (~NMI), U5.10 (~PFO)
/~RAM_CSI: U4.4 (IO30), U5.13 (~CE_IN)
/~RAM_CS: U3.22 (~CE), U5.12 (~CE_OUT)
/~RD: J3.25, U1.21 (~RD), U2.24 (~OE), U3.24 (~OE), U4.36 (IO24)
/~RESET: J3.20, RN2.4 (R3), U1.26 (~RESET), U4.1 (IN3/GCLRn), U5.15 (~RESET)
/~RFSH: J3.59, U1.28 (~RFSH)
/~ROM_CS: U2.22 (~CE), U4.5 (IO31)
/~WAIT: J3.65, RN2.6 (R5), U1.24 (~WAIT)
/~WR: J3.24, U1.22 (~WR), U2.31 (~WE), U3.29 (~WE), U4.40 (IO28)
GND: C1.2, C2.2, C3.1, C4.2, C5.2, C6.2, C7.2, J1.2, J2.2, J2.10, J3.17, J3.57, R1.2, R5.1, U1.29 (GND), U2.16 (GND), U3.16 (GND), U4.10 (GND), U4.22 (GND), U4.30 (GND), U4.42 (GND), U5.4 (GND), X1.4 (GND)
unnamed: D1.2 (A), R7.1
unnamed: R5.2, RV1.3
unnamed: R6.2, RV1.1
unnamed: RV1.2, U5.9 (PFI)
VCC: C1.1, C2.1, C4.1, C5.1, C6.1, C7.1, J2.4, J3.18, J3.58, R2.2, R3.2, R4.2, R6.1, R7.2, RN1.1 (common), RN2.1 (common), U1.11 (VCC), U2.32 (VCC), U4.3 (VCC), U4.15 (VCC), U4.23 (VCC), U4.35 (VCC), U5.3 (VCC), X1.8 (Vcc)

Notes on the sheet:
JTAG components are required for in-system CPLD programming. They are optional otherwise
Connect 3V to J1 for battery backed-up SRAM. Place a jumper over J1 if battery backup is not required.

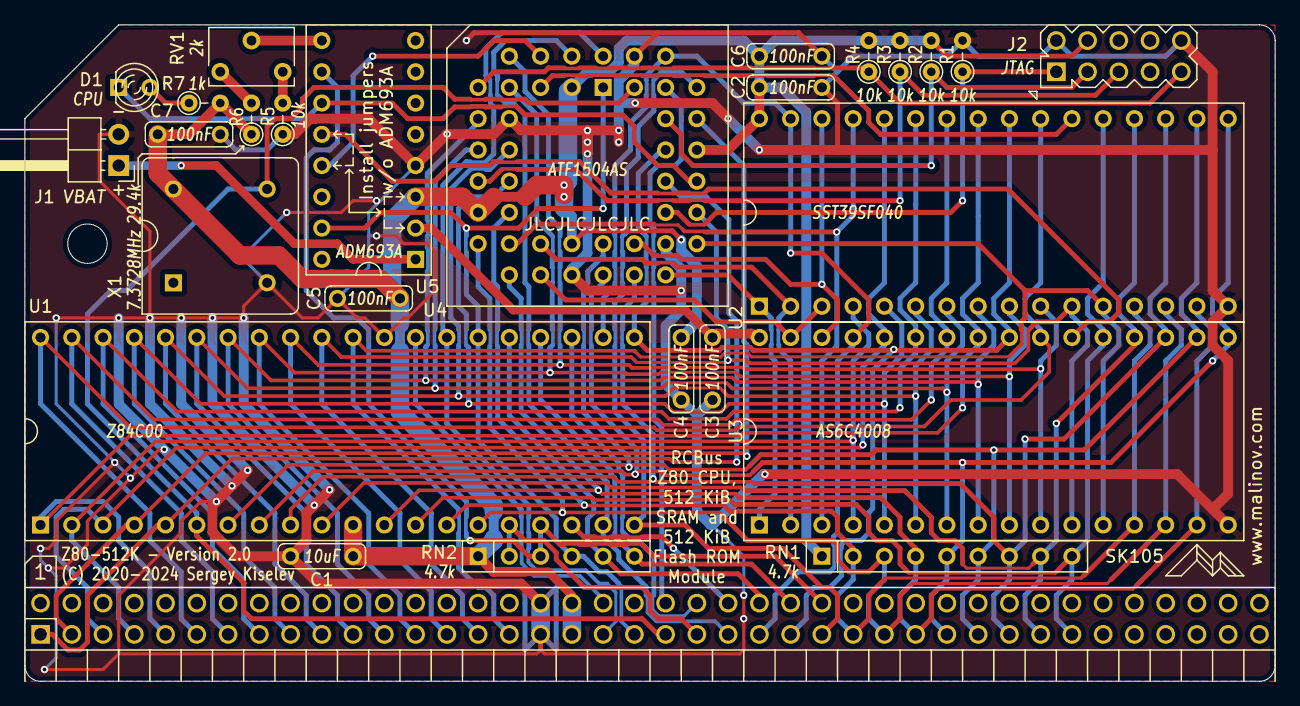
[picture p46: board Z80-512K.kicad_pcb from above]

Board: 2 copper layers, 101.6 x 53.3 mm, 29 parts (1 on the bottom side), 60 nets.

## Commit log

2021-01-05 README: Create BOM
2021-01-09 Upload KiCad and Gerber files
    [Z80-512K-B_Cu.gbr, Z80-512K-B_Mask.gbr, Z80-512K-B_Paste.gbr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]
2021-01-10 README: Update CPLD fuse map file paths
2021-01-10 Add photo of the board
2021-01-16 Update KiCad, gerber, and README for Version 1.1
    [Z80-512K-B_Cu.gbr, Z80-512K-B_Mask.gbr, Z80-512K-B_Paste.gbr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]
2021-01-22 Update CPLD files for PCB version 1.1
2021-01-25 CPLD: Add LED output multiplexed with watchdog
2021-01-26 Replace design files with version 1.2. Update README accordingly
    [Z80-512K-B_Cu.gbr, Z80-512K-B_Mask.gbr, Z80-512K-B_Paste.gbr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]
2021-01-28 README: Add parts for battery enclosure and connectors, add wishlist
2021-02-05 Add photo of the board v1.2
2021-02-05 Add PCB thumbnail image
2021-02-05 Building_Instructions: Add steps to build the board
2021-02-05 Add assembly steps photos
2021-02-05 Add pictures to the assembly steps
2021-02-05 Add Socket DIP16 photo
2021-02-05 Add link to assembly instructions
2021-02-06 Add PCB rendering
2021-02-06 Assembly_Instructions: Use resized images
2021-02-07 Add higher resolution battery holder photo
2021-02-08 Assembly_Instructions: Add note about resistor arrays' orientation
2021-02-08 KiCad: Remove comment about power fail components
    [Z80-512K.sch]
2021-02-12 Add alternative part numbers for the oscillator and resistor arrays
2021-03-02 README: Update PCB sources
2024-01-12 Update files for V2.0
    [Z80-512K-B_Cu.gbr, Z80-512K-B_Mask.gbr, Z80-512K-B_Paste.gbr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]
2024-01-30 Add assembly process photos for v2.0

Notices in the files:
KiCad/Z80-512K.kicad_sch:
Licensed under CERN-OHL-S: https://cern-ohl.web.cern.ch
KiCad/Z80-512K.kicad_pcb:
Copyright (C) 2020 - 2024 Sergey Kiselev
